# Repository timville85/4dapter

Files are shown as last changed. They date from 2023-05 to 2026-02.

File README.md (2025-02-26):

# 4dapter
### Open Source Controller Adapter for Nintendo Switch / MiSTer / XInput / Batocera / RetroArch

This project combines the NES, SNES, N64 and Genesis DaemonBite Retro Controllers projects together with a custom PCB to support 4 different controllers with a single socketed Arduino Pro Micro. PCB (KiCad + Gerbers), 3D Cases, and muliple firmware versions (Arduino code) all available in this repository.





PCB Kits + Fully Assembled units (with firmware of your choice) available on [Tindie](https://www.tindie.com/products/31785/)

3 different firmware versions are available in this repo:
* Default: Optimized for MiSTer, PC, Raspberry Pi, etc. - reports as 3 separate controllers (NES/SNES combined) and supports multiplayer from a single unit.
* Analogue Pocket: Optimized for Pocket Dock - reports as a single wired XInput device.
* Nintendo Switch: Optimized for Nintendo Switch Online NES, SNES, and Genesis collections - reports as a single wired switch controller.

**MiSTer Users - Important Info:** For maximum compatibly, install the MiSTer controller Map file found in the [MiSTer Maps Folder](https://github.com/timville85/4dapter/tree/main/MiSTer%20Maps) to your `/media/fat/config/inputs` directory on your MiSTer SD card and reboot your MiSTer. After doing this, you'll need to map the N64 controller in the N64 core for all buttons to work. The SNES / Genesis / NES cores will already be properly configured via the Map file.

## Resources and Thanks

**Special thanks to** [Dinierto Designs](https://twitter.com/DiniertoDesigns) **and** [Super Retro City X](https://twitter.com/SuperRetroCity) **for their assistance during development and testing of the 4dapter. Also thanks to** [Mechevarria](https://github.com/mechevarria) **for Batocera support and testing.**

**3D Case files were also designed by** [Dinierto Designs](https://twitter.com/DiniertoDesigns) **and are available in the 3D Cases folder.**

* [DaemonBite Retro Controllers](https://github.com/MickGyver/DaemonBite-Retro-Controllers-USB)
* https://github.com/esden/pretty-kicad-libs
* https://github.com/ddribin/nes-port-breadboard
* https://github.com/Biacco42/ProMicroKiCad
* http://www.neshq.com/hardgen/powerpad.txt
* https://www.instructables.com/Use-an-Arduino-with-an-N64-controller/

See individual README files in firmware folders for more specific instructions on button assignments and firmware configurations.

## Wiring Diagram
3dapter _ 4dapter Controller Wiring (1)

Current Draw Readings from DIO Pin 16 (used for 5v supply for DB9 port):
* Krikzz Joyzz:	38mA
* 8BitDo M30 2.4G: 29mA
* OEM SEGA 3-Button Wired: 3mA
* OEM SEGA 6-Button Wired: 3mA
* Retrobit 6-Button Wired: 2mA
(Arduino DIO Max Rated Current: 40mA)

## Tested Controllers

The following controllers have been personally tested and are supported with the Triple Controller. All listed devices also fit when using the 3D Case as well.

NES:
* OEM NES Controller
* OEM NES PowerPad (Default FW Only)
* 8BitDo N30 2.4G Receiver
* 8BitDo NES Retro Receiver

SEGA / Genesis:
* OEM SEGA Master System 2-Button Controller
* OEM Genesis 3-Button Controller
* OEM Genesis 6-Button Controller
* 8BitDo M30 2.4G Receiver
* 8BitDo Genesis Retro Receiver
* Krikzz Joyzz

SNES:
* OEM SNES Controller
* OEM SFC Controller
* OEM SNES NTT Controller (Default FW Only)
* 8BitDo SN30 2.4G Receiver
* 8BitDo SNES Retro Receiver

N64:
* OEM N64 Controller
* Retro Fighters Brawler64 V1/V2
* Retro Fighters Brawler64 Wireless Edition

## 4dapter Bill of Materials (BOM)

4dapter was designed with all components to be through-hole soldered to make the project as accessible as possible.

* **1x 4dapter Main Board**

* **1x 4dapter N64 Daugher Board**

* **1x SNES Socket (90 deg):** [AliExpress - Gamers Zone Store](https://www.aliexpress.com/item/32838396935.html) 

* **1x NES Socket:** [AliExpress - Gamers Zone Store](https://www.aliexpress.com/item/1005003699734963.html)

* **1x Genesis Socket:** [AliExpress - Gamers Zone Store](https://www.aliexpress.com/item/1005003699497865.html)

* **1X N64 Socket:** [AliExpress - Gamers Zone Store](https://www.aliexpress.us/item/3256803534347876.html)

* **1x Arduino Pro Micro (USB-C 3-15V Version):** [AliExpress](https://www.aliexpress.us/item/2251832700923799.html)

* **1x 1x3 90 Degree Male Header:** [Digi-Key](https://www.digikey.com/en/products/detail/sullins-connector-solutions/PREC003SBAN-M71RC/2774931)

* **1x 3.3v Regulator (MCP1700-3302E/TO):** [Digi-Key](https://www.digikey.com/en/products/detail/microchip-technology/MCP1700-3302E-TO/652680)

* **2x 1uF Capacitor:** [Digi-Key](https://www.digikey.com/en/products/detail/tdk-corporation/FG18X5R1H105KRT06/5802871) 

* **1x 6mm x 6mm x 5mm Push Button:** [Digi-Key](https://www.digikey.com/en/products/detail/te-connectivity-alcoswitch-switches/1825910-6/1632536)

* **2x 1x12 Female Header:** [Digi-Key](https://www.digikey.com/en/products/detail/sullins-connector-solutions/PPTC121LFBN-RC/807231)

* **5x M2x10mm Screws for 3D Case**




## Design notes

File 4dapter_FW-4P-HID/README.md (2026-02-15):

# 4dapter - 4 Player HID Firmware variation for MiSTer / PC

This firmware reports **four controller ports as separate USB HID gamepads** (four players on one device):

- **Gamepad 0:** NES  
- **Gamepad 1:** SNES  
- **Gamepad 2:** Genesis  
- **Gamepad 3:** N64  

**Recommended for MiSTer:** This 4-endpoint firmware is designed and optimized for MiSTer FPGA devices, where all four controller ports are correctly recognized. For PC or browser use, fewer endpoints may appear (see [Windows](#windows-only-3-controllers-visible-same-firmware-shows-4-on-maclinux) and [browser](#browser-gamepad-api) limitations below).

To get all four endpoints, **CDC (USB serial) must be disabled** at build time. See [Build setup (4 HID endpoints)](#build-setup-4-hid-endpoints) below.

**Windows:** On Windows, only 3 controller endpoints may appear even with correct firmware—this may be a [Windows limitation](#windows-only-3-controllers-visible-same-firmware-shows-4-on-maclinux).

---

## Build Setup (4 HID Endpoints)

The ATmega32U4 has limited USB endpoints. With serial (CDC) enabled, only three HID gamepads are available and the N64 port will not appear. To get all four gamepads you must build the Arduino AVR core with `CDC_DISABLED`.

### 1. Copy `platform.local.txt` into the AVR platform folder

This folder includes **`platform.local.txt`**. Copy it into the **same folder as the AVR platform** your Arduino IDE uses.

To find that folder: enable **File → Preferences → Show verbose output during compilation**, then compile once and look for a line like **“Using core ... from platform in folder: ...”**. The path is the folder that should contain `platform.local.txt`.

Example (your path may differ by OS or Arduino version):

- **macOS:** `~/Library/Arduino15/packages/arduino/hardware/avr/1.8.7/`
- **Windows:** `%LOCALAPPDATA%\Arduino15\packages\arduino\hardware\avr\1.8.7\`
- **Linux:** `~/.arduino15/packages/arduino/hardware/avr/1.8.7/`

**If you build on multiple computers (e.g. Mac and Windows), you must add `platform.local.txt` and clear the build cache on each machine.** Otherwise you may see 4 controller endpoints on one and only 3 on the other, because the firmware was compiled with different options (CDC on vs off).

Copy the **`platform.local.txt`** from this folder into that AVR folder (so the file sits next to `platform.txt`).

### 2. Clear the build cache and recompile

The IDE may still use an old core built without `-DCDC_DISABLED`. After adding `platform.local.txt`:

1. Quit the Arduino IDE.
2. Delete the build cache folder (its path appears in the verbose compile output as **“-build-cache ...”**).
3. Reopen the IDE, open this sketch, and run **Sketch → Verify/Compile**.

In the verbose log you should see **`-DCDC_DISABLED`** when the core is compiled. Then all four HID gamepads (including N64) will register.

### 3. Uploading (no serial port)

With CDC disabled, the board no longer appears as a serial port. To upload:

1. Start upload from the IDE.
2. When it says “Uploading…”, **press the reset button** on the 4dapter PCB. The board enters the bootloader and the upload completes.

---

## Windows: only 3 controllers visible (same firmware shows 4 on Mac/Linux)

If the **same 4dapter hardware** (with 4-endpoint firmware already flashed) shows **4 controller endpoints on macOS or Linux** but only **3 on Windows**, this appears to be a **Windows limitation**, not a firmware bug.

The device correctly reports 4 HID interfaces and 4 endpoints (verified with USBView: `bNumInterfaces = 4`, `wTotalLength` validated, all 4 interface and endpoint descriptors present). Windows’ USB composite parent driver (Usbccgp.sys) and HID stack only create 3 child devices for the 4 interfaces. IADs were tried but reverted—`bInterfaceCount=1` is invalid per USB spec and did not resolve the issue. The firmware uses plain interface descriptors and is spec-compliant.

**Things to try on Windows (may or may not help):**

1. **Device Manager** — Expand **Human Interface Devices** and **Universal Serial Bus devices**. Check how many 4dapter entries appear and whether any show a yellow warning.
2. **USB port** — Plug directly into a **motherboard USB port** (not a hub).
3. **Driver** — If an interface appears under **Other devices** or with a warning, try **Update driver** → **Let me pick** → **HID-compliant game controller** or **USB Input Device**.
4. **Verify descriptor** — Use [USBView](https://learn.microsoft.com/en-us/windows-hardware/drivers/usbcon/usbview-example) or [USB Device Tree Viewer](https://www.uwe-sieber.de/usbtreeview.html). If `bNumInterfaces = 4` and all 4 interfaces/endpoints are present with no errors, the firmware is correct; the limitation is in Windows’ enumeration.

### Browser (Gamepad API)

In browser gamepad testers (e.g. [Hardware Tester](https://hardwaretester.com/gamepad)) using the Gamepad API:

- **Chrome on macOS:** Only **1** controller may appear. The 4dapter is one USB composite device; Chrome on Mac often exposes a single gamepad slot per device, so only one of the four ports is visible.
- **Chrome on Windows:** **3** controllers typically appear, matching the 3 HID interfaces that Windows enumerates for this device.

This is browser/OS behavior, not a firmware bug. Click on the page (user gesture) and press a button on a connected port so the browser can detect the controller.

### Custom descriptor with IADs (reference)

IADs group **two or more** interfaces into one function; `bInterfaceCount` must be &gt; 1 per USB spec. With one interface per gamepad, IAD cannot be used correctly—each IAD would need `bInterfaceCount=1`, which USBView flags as an error. This section documents the format for reference only. Each interface remains **HID** (`bInterfaceClass = 0x03`). Each interface keeps `bInterfaceClass = 0x03` (HID); the IAD is an extra descriptor that *precedes* each interface and tells the host “the following interface(s) form one function.” That helps Windows’ composite driver create one PDO per gamepad. The host still loads the standard HID driver for each interface; games and apps still see four HID game controllers.

**Current layout (no IAD):**  
For each of the four gamepads, the configuration descriptor contains:

1. **Interface descriptor** (9 bytes) — `bInterfaceClass = 0x03` (HID), one interface, one endpoint.
2. **HID descriptor** (class-specific) — report descriptor length, etc.
3. **Endpoint descriptor** (7 bytes) — interrupt IN.

So today: `[Interface][HID][Endpoint]` × 4. No IAD.

**With IAD (custom descriptor):**  
Before each of those blocks you prepend an **IAD** (8 bytes) that describes “one function = one HID interface”:

| Offset | Field | Value (per gamepad) | Meaning |
|---|---|---|---|
| 0 | bLength | 8 | IAD size |
| 1 | bDescriptorType | 0x0B | INTERFACE_ASSOCIATION |
| 2 | bFirstInterface | 0, 1, 2, or 3 | Interface number for this pad |
| 3 | bInterfaceCount | 1 | One interface in this function |
| 4 | bFunctionClass | 0x03 | HID |
| 5 | bFunctionSubClass | 0x00 | No subclass |
| 6 | bFunctionProtocol | 0x00 | No protocol |
| 7 | iFunction | 0 | No string (or index if you add one) |

So each gamepad’s block becomes: **`[IAD][Interface][HID][Endpoint]`**. The Interface descriptor is unchanged: still class 0x03 (HID), so the device still reports as a HID device. Only the configuration descriptor gains four 8-byte IADs; the rest (HID report descriptor, endpoints, behavior) stays the same.

**Example IAD bytes for interface 0 (NES):**  
`08 0B 00 01 03 00 00 00`

- `08` = length 8  
- `0B` = IAD  
- `00` = bFirstInterface 0  
- `01` = bInterfaceCount 1  
- `03 00 00` = HID, no subclass, no protocol  
- `00` = iFunction 0  

For interfaces 1–3 you’d use `08 0B 01 01 03 00 00 00`, `08 0B 02 01 03 00 00 00`, `08 0B 03 01 03 00 00 00`.

**Optional device descriptor change:**  
Some hosts expect composite devices that use IADs to use device class **EFh** (Miscellaneous), subclass **02h** (Common Class), protocol **01h** (Interface Association). That is a device-level hint that IADs are present; the interfaces remain HID (0x03). If you implement a fully custom descriptor set, you can set `bDeviceClass=0x00` (composite) as today, or `0xEF/0x02/0x01` if you want to follow that convention.

**Summary:** A custom descriptor that adds IADs would still report four HID interfaces; only the configuration descriptor layout changes. The device would still be a standard HID gamepad device to the host and to games.

---

## MiSTer - Define Joystick Buttons (Mapping)

In the MiSTer main menu, use the N64 controller for the steps below; NES / SNES / Genesis will then align for their cores:

```
DPAD Test: Press RIGHT     ---  D-Right
Stick 1 Test: Tilt RIGHT   ---  Analog Stick Right
Stick 1 Test: Tilt DOWN    ---  Analog Stick Down
Stick 2 Test: Tilt RIGHT   ---  Undefine (User / Space to Skip)
Press: RIGHT               ---  Analog Stick Right
Press: LEFT                ---  Analog Stick Left
Press: DOWN                ---  Analog Stick Down
Press: UP                  ---  Analog Stick Up
Press: A                   ---  A Button
Press: B                   ---  B Button
Press: X                   ---  C-Down Button
Press: Y                   ---  C-Left Button
Press: L                   ---  Left Bumper Button
Press: R                   ---  Right Bumper Button
Press: Select              ---  C-Right Button
Press: Start               ---  Start Button
Press: Mouse Move RIGHT    ---  Undefine (User / Space to Skip)
Press: Mouse Move LEFT     ---  Undefine (User / Space to Skip)
Press: Mouse Move DOWN     ---  Undefine (User / Space to Skip)
Press: Mouse Move UP       ---  Undefine (User / Space to Skip)
Press: Mouse Btn Left      ---  Undefine (User / Space to Skip)
Press: Mouse Btn Right     ---  Undefine (User / Space to Skip)
Press: Mouse Btn Middle    ---  Undefine (User / Space to Skip)
Press: Mouse Emu/Sniper    ---  Undefine (User / Space to Skip)
Press: Menu                ---  C-Right Button + Analog Stick Down
Note: C-Right Button + Analog Stick Down makes Select/Mode + Down work for NES/SNES/GEN
      This may cause menu to appear in some gameplay, so adapt as needed.
Press: Menu: OK            ---  A Button
Press: Menu: Back          ---  B Button
Stick 1: Tilt RIGHT        ---  Analog Stick Right
Stick 1: Tilt DOWN         ---  Analog Stick Down
```

---

## Controller Button Mapping

To keep button mapping consistent on MiSTer, map the SNES controller in the MiSTer main menu; NES and Genesis will then align to their core defaults.

```
     NES    PowerPad  SNES     GEN(normal)  N64
-------------------------------------------------------
X    U/D    N/A       U/D      U/D          Stick U/D
Y    L/R    N/A       L/R      L/R          Stick L/R
01   B      Pad 01    B        B            B
02   A      Pad 02    A        A            A
03   N/A    Pad 03    Y        Y            C-Left
04   N/A    Pad 04    X        X            C-Down
05   N/A    Pad 05    L        Z            L
06   N/A    Pad 06    R        C            R
07   SELECT Pad 07    SELECT   MODE         C-Right
08   START  Pad 08    START    START        START
09   N/A    Pad 09    NTT 0    HOME(8BitDo) Z
10   N/A    Pad 10    NTT 1    N/A          D-Up
11   N/A    Pad 11    NTT 2    N/A          D-Down
12   N/A    Pad 12    NTT 3    N/A          D-Left
13   N/A    N/A       NTT 4    N/A          D-Right
14   N/A    N/A       NTT 5    N/A          C-Up
15   N/A    N/A       NTT 6    N/A          N/A 
16   N/A    N/A       NTT 7    N/A          N/A
17   N/A    N/A       NTT 8    N/A          N/A
18   N/A    N/A       NTT 9    N/A          N/A
19   N/A    N/A       NTT *    N/A          N/A
20   N/A    N/A       NTT #    N/A          N/A
21   N/A    N/A       NTT .    N/A          N/A
22   N/A    N/A       NTT C    N/A          N/A
23   N/A    N/A       N/A      N/A          N/A
24   N/A    N/A       NTT End  N/A          N/A
```

---

## MiSTer Home Menu Suggestion

If you use the [mapping steps](#mister---define-joystick-buttons-mapping) above (with Menu → C-Right Button + Analog Stick Down for N64), then:

* **N64:** C-Right Button + Analog Stick Down  
* **NES:** SELECT + DOWN  
* **SNES:** SELECT + DOWN  
* **GENESIS:** MODE + DOWN  

*Note: SELECT + DOWN = HOME on 8BitDo N30*

---

## RetroArch Port Binding

The 4dapter appears as one USB device with four controller indices. In RetroArch, set **Settings → Input → Port 1 Binds → Device Index** and choose the index for the port you want (e.g. #4 for N64, #1–#3 for NES/SNES/Genesis). Save; it applies per game, core, or content directory.

- https://retropie.org.uk/forum/topic/26681/port-binds/
- https://retropie.org.uk/docs/RetroArch-Configuration/#core-input-remapping

---

## Install Instructions

### 1. Complete build setup (4 HID endpoints)

Follow [Build Setup (4 HID endpoints)](#build-setup-4-hid-endpoints) above: copy **`platform.local.txt`** into the AVR platform folder and clear the build cache.

### 2. Board and upload

1. In the Arduino IDE, select **Tools → Board → Arduino AVR Boards → Arduino Leonardo**.
2. Open this sketch and compile (Sketch → Verify/Compile).
3. Upload using the reset-button method described in step 3 of Build Setup.

---

## Restoring Firmware After Alternative Firmware

If you previously flashed Analogue Pocket or Nintendo Switch firmware, the board may no longer show as a serial port. The 4dapter HID firmware (with CDC disabled) also does not use serial.

To upload or restore firmware:

1. Open this project in the Arduino IDE.
2. Connect the 4dapter via USB.
3. Start upload (Sketch → Upload).
4. When the IDE says “Uploading…”, **press the reset button** on the 4dapter PCB. The board enters the bootloader and the upload should complete. If the port is not found, try the upload and reset sequence again.

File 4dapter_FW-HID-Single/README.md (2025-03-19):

# 4dapter - HID Firmware (Single) for Batocera / PC

The default HID firmware will allow the 4dapter to appear as a single controller with all 4 inputs merged into one.

## [Batocera](https://batocera.org/)
This firmware will allow usage of the 4dapter in Batocera by **default** - no code changes are required for this flavor of the 4dapter firmware. 

This compatibility happens by setting 2 lines to `false`. The first is in [4dapter_FW-HID-Single.ino](4dapter_FW-HID-Single.ino)
```c++
#define N64Mister       false
```

The second is in [SegaController32U4.h](SegaController32U4.h)
```c++
#define GEN_MISTER       false
```

NES, SNES, Genesis controllers will be mapped automatically for immediate use. N64 controllers will need to be re-mapped in Retroarch (Mupen64Plus-Next) according to the diagram below
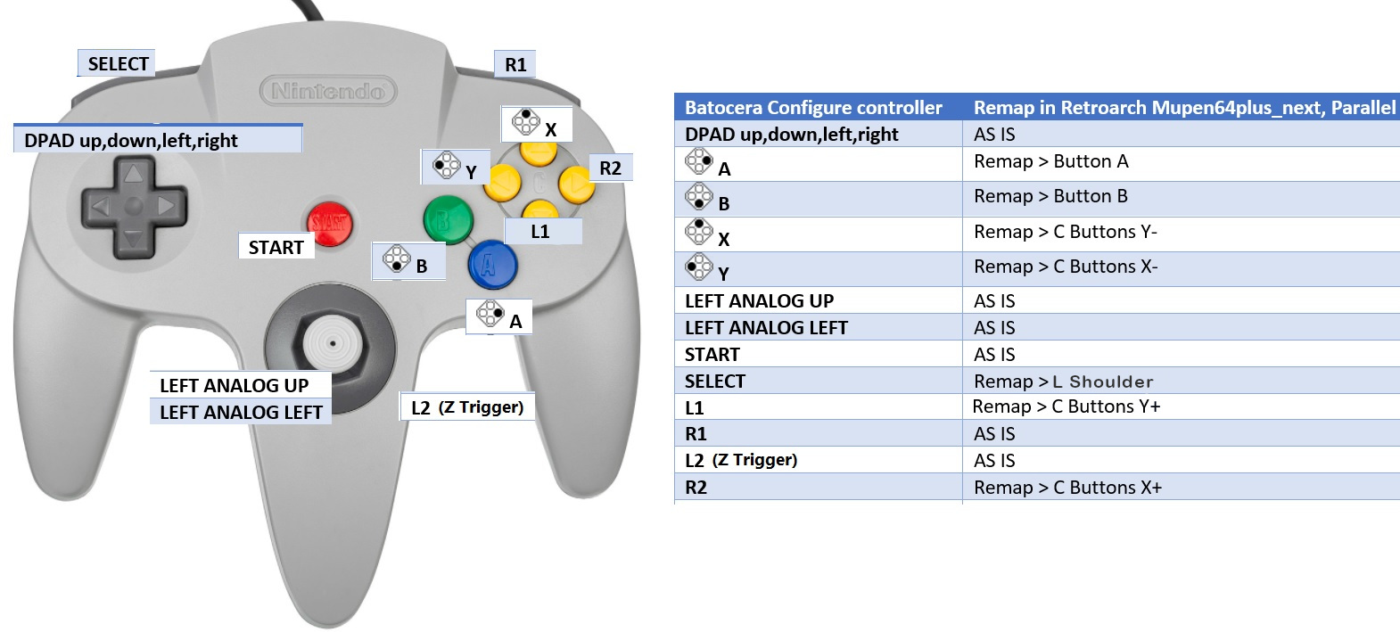
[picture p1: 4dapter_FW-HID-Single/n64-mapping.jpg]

An example re-map for player 1 is in [Mupen64Plus-Next.rmp](Mupen64Plus-Next.rmp) which can be manually copied to `/userdata/system/.config/retroarch/config/remaps/Mupen64Plus-Next`

### Older versions of Batocera
This mapping will be added to Batocera in version 42+ but can be manually added to your `/userdata/system/configs/emulationstation/es_input.cfg` with the content in [es_last_input.cfg](es_last_input.cfg)

## MiSTer - Define Joystick Buttons (Mapping)

### Manual Mapping
If manually mapping in the MiSTer main menu, use the N64 controller using the following steps and NES / SNES / Genesis will be appropriately mapped for their cores:

```
DPAD Test: Press RIGHT     ---  D-Right
Stick 1 Test: Tilt RIGHT   ---  Analog Stick Right
Stick 1 Test: Tilt DOWN    ---  Analog Stick Down
Stick 2 Test: Tilt RIGHT   ---  Undefine (User / Space to Skip)
Press: RIGHT               ---  Analog Stick Right
Press: LEFT                ---  Analog Stick Left
Press: DOWN                ---  Analog Stick Down
Press: UP                  ---  Analog Stick Up
Press: A                   ---  A Button
Press: B                   ---  B Button
Press: X                   ---  C-Down Button
Press: Y                   ---  C-Left Button
Press: L                   ---  Left Bumper Button
Press: R                   ---  Right Bumper Button
Press: Select              ---  C-Right Button
Press: Start               ---  Start Button
Press: Mouse Move RIGHT    ---  Undefine (User / Space to Skip)
Press: Mouse Move LEFT     ---  Undefine (User / Space to Skip)
Press: Mouse Move DOWN     ---  Undefine (User / Space to Skip)
Press: Mouse Move UP       ---  Undefine (User / Space to Skip)
Press: Mouse Btn Left      ---  Undefine (User / Space to Skip)
Press: Mouse Btn Right     ---  Undefine (User / Space to Skip)
Press: Mouse Btn Middle    ---  Undefine (User / Space to Skip)
Press: Mouse Emu/Sniper    ---  Undefine (User / Space to Skip)
Press: Menu                ---  C-Right Button + Analog Stick Down
Note: C-Right Button + Analog Stick Down makes Select/Mode + Down work for NES/SNES/GEN
      This may cause menu to appear in some gameplay, so adapt as needed.
Press: Menu: OK            ---  A Button
Press: Menu: Back          ---  B Button
Stick 1: Tilt RIGHT        ---  Analog Stick Right
Stick 1: Tilt DOWN         ---  Analog Stick Down
```

## Controller Button Mapping

```
     NES    PowerPad  SNES     GEN(normal)  GEN(MiSTer)  N64
-------------------------------------------------------------------
X    U/D    N/A       U/D      U/D          U/D          Stick U/D
Y    L/R    N/A       L/R      L/R          L/R          Stick L/R
01   B      Pad 01    B        B            A            B
02   A      Pad 02    A        A            B            A
03   N/A    Pad 03    Y        Y            X            C-Left
04   N/A    Pad 04    X        X            Y            C-Down
05   N/A    Pad 05    L        Z            Z            L
06   N/A    Pad 06    R        C            C            R
07   SELECT Pad 07    SELECT   MODE         MODE         C-Right
08   START  Pad 08    START    START        START        START
09   N/A    Pad 09    NTT 0    HOME(8BitDo) [SPECIAL]    Z
10   N/A    Pad 10    NTT 1    N/A          N/A          D-Up
11   N/A    Pad 11    NTT 2    N/A          N/A          D-Down
12   N/A    Pad 12    NTT 3    N/A          N/A          D-Left
13   N/A    N/A       NTT 4    N/A          N/A          D-Right
14   N/A    N/A       NTT 5    N/A          N/A          C-Up
15   N/A    N/A       NTT 6    N/A          N/A          N/A
16   N/A    N/A       NTT 7    N/A          N/A          N/A
17   N/A    N/A       NTT 8    N/A          N/A          N/A
18   N/A    N/A       NTT 9    N/A          N/A          N/A
19   N/A    N/A       NTT *    N/A          N/A          N/A
20   N/A    N/A       NTT #    N/A          N/A          N/A
21   N/A    N/A       NTT .    N/A          N/A          N/A
22   N/A    N/A       NTT C    N/A          N/A          N/A
23   N/A    N/A       N/A      N/A          N/A          N/A
24   N/A    N/A       NTT End  N/A          N/A          N/A

* GENESIS(MiSTer): Mode will send Select + Down
```

## MiSTer Home Menu Suggestion
* **NES:** SELECT + DOWN
* **SNES:** SELECT + DOWN
* **GENESIS:** MODE + DOWN

*Note: SELECT + DOWN = HOME on 8BitDo N30*

## MiSTer mode on 8bitdo M30 controller

MiSTer mode can be toggled on and off with "HOME + Z" (you have to press HOME first, Z second). This setting is saved to EEPROM and preserved across power cycles. The default is "normal mode".

When the Genesis controller is in MiSTer mode:

- The HOME button sends "DOWN + MODE" (This is because no equivalent of the HOME button exists on the other controller ports)

- Buttons are swapped: A with B and X with Y. This is such that the position of the buttons is consistent between SNES and Genesis.

## Install Instructions
You can update the firmare using [Arduino IDE](https://www.arduino.cc/en/software)

From Arudino IDE, `file -> open` then select [4dapter_FW-HID-Single](4dapter_FW-HID-Single)

### 1. Select "Arduino AVR Boards - Arduino Leonardo" from Boards List
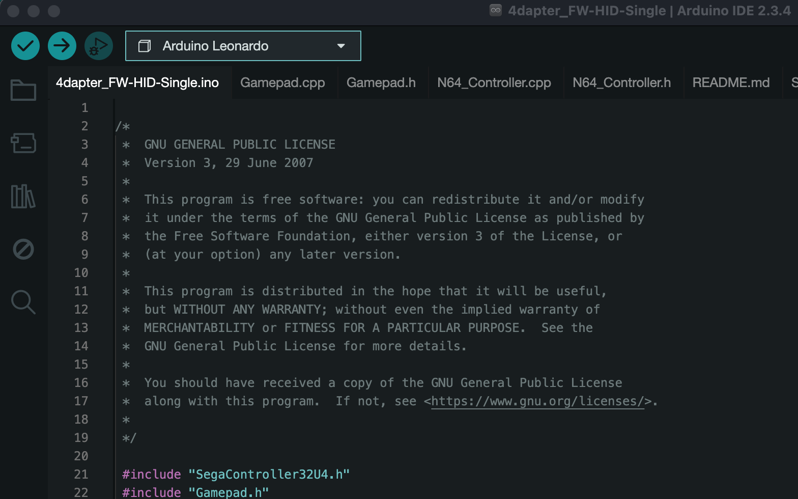
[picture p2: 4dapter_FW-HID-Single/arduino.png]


### 2. Download project to Arduino Pro Micro board
Select `upload` in the Arduino IDE
> You will need to manually reset by pressing the tip of a flatheader screwdriver for 1 second on the board after selecting `upload` by following the instructions below 

## Restoring Firmware After Alternative Firmware Downloads

If you previously used the Analogue Pocket or Nintendo Switch firmware versions, your Arduino Pro Micro will no longer report as a Serial device and will not appear in the "Port" list in the Arduino software. Using the default 3dapter firmware does not suffer from this issue.

To restore the default firmware for your Arduino Pro Micro, you will need to manually reset the Arduino Pro Micro by shorting the Reset + Ground pins together to trigger a reset. 

1. Open the default firmware project in the Arduino software.
2. Connect your Arduino Pro Micro to your computer.
3. Trigger the download from the Arduino software. The Arduino software will first compile the project before beginning the download.
4. Once the "compiling" step has finished, trigger a reset on the Arduino Pro Micro by briefly touching the Reset (RST) and Ground (GND) pins together. This should make the Arduino forcefully switch into bootloader mode and allow the download to complete. If the download fails initially due to not finding the COM port, repeat the download/reset process and it should work the second time.

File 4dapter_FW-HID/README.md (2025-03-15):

# 4dapter - HID Firmware for MiSTer / PC

The default HID firmware will allow the 4dapter to appear a multiplayer input controller with 3 controller inputs acting as it's own separate player/input (NES and SNES are combined due to Arduino USB endpoint limitations.)

## MiSTer - Define Joystick Buttons (Mapping)

### Via .map File
For maximum compatibly, install the MiSTer controller Map file found in the [MiSTer Maps Folder](https://github.com/timville85/4dapter/tree/main/MiSTer%20Maps) to your `/media/fat/config/inputs` directory on your MiSTer SD card and reboot your MiSTer. After doing this, you'll need to map the N64 controller in the N64 core for all buttons to work. The SNES / Genesis / NES cores will already be properly configured via the Map file, so do not map the individual cores or else conflicts may occur.

### Manual Mapping 
If manually mapping in the MiSTer main menu, use the N64 controller using the following steps and NES / SNES / Genesis will be appropriately mapped for their cores:
```
DPAD Test: Press RIGHT     ---  D-Right
Stick 1 Test: Tilt RIGHT   ---  Analog Stick Right
Stick 1 Test: Tilt DOWN    ---  Analog Stick Down
Stick 2 Test: Tilt RIGHT   ---  Undefine (User / Space to Skip)
Press: RIGHT               ---  Analog Stick Right
Press: LEFT                ---  Analog Stick Left
Press: DOWN                ---  Analog Stick Down
Press: UP                  ---  Analog Stick Up
Press: A                   ---  A Button
Press: B                   ---  B Button
Press: X                   ---  C-Down Button
Press: Y                   ---  C-Left Button
Press: L                   ---  Left Bumper Button
Press: R                   ---  Right Bumper Button
Press: Select              ---  C-Right Button
Press: Start               ---  Start Button
Press: Mouse Move RIGHT    ---  Undefine (User / Space to Skip)
Press: Mouse Move LEFT     ---  Undefine (User / Space to Skip)
Press: Mouse Move DOWN     ---  Undefine (User / Space to Skip)
Press: Mouse Move UP       ---  Undefine (User / Space to Skip)
Press: Mouse Btn Left      ---  Undefine (User / Space to Skip)
Press: Mouse Btn Right     ---  Undefine (User / Space to Skip)
Press: Mouse Btn Middle    ---  Undefine (User / Space to Skip)
Press: Mouse Emu/Sniper    ---  Undefine (User / Space to Skip)
Press: Menu                ---  C-Right Button + Analog Stick Down
Note: C-Right Button + Analog Stick Down makes Select/Mode + Down work for NES/SNES/GEN
      This may cause menu to appear in some gameplay, so adapt as needed.
Press: Menu: OK            ---  A Button
Press: Menu: Back          ---  B Button
Stick 1: Tilt RIGHT        ---  Analog Stick Right
Stick 1: Tilt DOWN         ---  Analog Stick Down
```

## Controller Button Mapping

To maintain proper button mapping on MiSTer, it's recommended to map the SNES controller on the MiSTer Main menu and the NES / Genesis controllers will align to their core defaults properly.

```
     NES    PowerPad  SNES     GEN(normal)  GEN(MiSTer)  N64
-------------------------------------------------------------------
X    U/D    N/A       U/D      U/D          U/D          Stick U/D
Y    L/R    N/A       L/R      L/R          L/R          Stick L/R
01   B      Pad 01    B        B            A            B
02   A      Pad 02    A        A            B            A
03   N/A    Pad 03    Y        Y            X            C-Left
04   N/A    Pad 04    X        X            Y            C-Down
05   N/A    Pad 05    L        Z            Z            L
06   N/A    Pad 06    R        C            C            R
07   SELECT Pad 07    SELECT   MODE         MODE         C-Right
08   START  Pad 08    START    START        START        START
09   N/A    Pad 09    NTT 0    HOME(8BitDo) [SPECIAL]    Z
10   N/A    Pad 10    NTT 1    N/A          N/A          D-Up
11   N/A    Pad 11    NTT 2    N/A          N/A          D-Down
12   N/A    Pad 12    NTT 3    N/A          N/A          D-Left
13   N/A    N/A       NTT 4    N/A          N/A          D-Right
14   N/A    N/A       NTT 5    N/A          N/A          C-Up
15   N/A    N/A       NTT 6    N/A          N/A          N/A
16   N/A    N/A       NTT 7    N/A          N/A          N/A
17   N/A    N/A       NTT 8    N/A          N/A          N/A
18   N/A    N/A       NTT 9    N/A          N/A          N/A
19   N/A    N/A       NTT *    N/A          N/A          N/A
20   N/A    N/A       NTT #    N/A          N/A          N/A
21   N/A    N/A       NTT .    N/A          N/A          N/A
22   N/A    N/A       NTT C    N/A          N/A          N/A
23   N/A    N/A       N/A      N/A          N/A          N/A
24   N/A    N/A       NTT End  N/A          N/A          N/A

* GENESIS(MiSTer): Mode will send Select + Down
```

## MiSTer Home Menu Suggestion
* **NES:** SELECT + DOWN
* **SNES:** SELECT + DOWN
* **GENESIS:** MODE + DOWN

*Note: SELECT + DOWN = HOME on 8BitDo N30*

## MiSTer mode on 8bitdo M30 controller

The 4dapter exposes three "players" on one USB device.  Unfortunately MiSTer does not support setting keymaps per "player", MiSTer mode works around this by making sure the positional mapping is the same between all controllers.

MiSTer mode can be toggled on and off with "HOME + Z" (you have to press HOME first, Z second). This setting is saved to EEPROM and preserved across power cycles. The default is "normal mode".

When the Genesis controller is in MiSTer mode:

- The HOME button sends "DOWN + MODE" (This is because no equivalent of the HOME button exists on the other controller ports)

- Buttons are swapped: A with B and X with Y. This is such that the position of the buttons is consistent between SNES and Genesis.

## Retroarch Port Binding

Some Retroarch users have reported issues regarding setting the correct “Device Index” setting, since the 3dapter reports a single “device” to RetroArch with 3 different controllers, each as their own “index”.

In Retroarch, go to Settings → Input → Port 1 Binds → Device Index and then choose #3 for N64 and presumably #1 or #2 for NES/SNES and Genesis. Save and it sticks for that game, core or content directory.

https://retropie.org.uk/forum/topic/26681/port-binds/
https://retropie.org.uk/docs/RetroArch-Configuration/#core-input-remapping

## Install Instructions

### 1. Select "Arduino AVR Boards - Arduino Leonardo" from Boards List

### 2. Download project to Arduino Pro Micro board

## Restoring Firmware After Alternative Firmware Downloads

If you previously used the Analogue Pocket or Nintendo Switch firmware versions, your Arduino Pro Micro will no longer report as a Serial device and will not appear in the "Port" list in the Arduino software. Using the default 3dapter firmware does not suffer from this issue.

To restore the default firmware for your Arduino Pro Micro, you will need to manually reset the Arduino Pro Micro by shorting the Reset + Ground pins together to trigger a reset. 

1. Open the default firmware project in the Arduino software.
2. Connect your Arduino Pro Micro to your computer.
3. Trigger the download from the Arduino software. The Arduino software will first compile the project before beginning the download.
4. Once the "compiling" step has finished, trigger a reset on the Arduino Pro Micro by briefly touching the Reset (RST) and Ground (GND) pins together. This should make the Arduino forcefully switch into bootloader mode and allow the download to complete. If the download fails initially due to not finding the COM port, repeat the download/reset process and it should work the second time.

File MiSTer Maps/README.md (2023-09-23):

# 4dapter - MiSTer Map Files

**For maximum compatibly, install the MiSTer controller Map file found in the MiSTer Maps Folder to your `/media/fat/config/inputs` directory on your MiSTer SD card and reboot your MiSTer**

### Firmware button layouts for N64 controllers were updated on September 23rd 2023
Please update your firmware using the Arduino IDE software to use the `Latest` folder map files , otherwise please use the `Pre Sept 23 2023 FW` folder map file!

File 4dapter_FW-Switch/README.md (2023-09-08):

# 4dapter - Nintendo Switch Firmware

This firmware will allow the 4dapter to appear a single Switch-compatible controller. All 4 controller inputs will share the same singular player input (i.e. use only one controller at time). 

The controller inputs have been mapped to align to map to the Nintendo Switch Virtual NES, SNES, N64 and Genesis apps. Switch-specific button combos have been added to support in-game menus, home buttons, and screenshot capabities.

## IMPORTANT NOTE
**Installing the XInput Library will remove the self-reset listener from the Arduino board. This means you will need to manually reset the Arduino when updating the code on the board or switching to a different firmware.**

**You can accomplish this by connecting the RST and GND pins together - a tip of a screwdriver works well since the pins are next to each other.**



## 4dapter Special Buttons for Switch

**NES:**
* In-Game Menu ("-" Button): Select + D-Pad Down
* Home Button: Select + Start
* Screenshot: Select + Up

**SNES:**
* In-Game Menu ("-" Button): Select + D-Pad Down
* Home Button: Select + Start
* Screenshot: Select + Up

**Genesis (6-Button Mode):**
* In-Game Menu ("-" Button): Mode + Down
* Home Button: Mode + Start (or 8BitDo M30 Heart Button)
* Screenshot: Mode + D-Pad Up
* Special Mode to Swap Genesis X --> Switch RB (for SEGA Genesis Classics): Hold Mode + B for 1.5 Seconds

**Genesis (3-Button Mode):**
* In-Game Menu ("-" Button): Start + A + B + C
* Home Button: Start + A + Down
* Screenshot: Start + A + Up

**N64:**
* In-Game Menu ("-" Button): Start + D-Pad Down
* Home Button: Start + L-Button + R-Button
* Screenshot: Start + D-Pad Up
* Special Mode to Swap N64 B --> Switch X (for Super Mario 3D All-Stars): Hold Start + D-Pad Down for 1.5 Seconds

**NES / SNES / Genesis 6-Button:**
Swap Directional Pad <--> Left Analog Joystick Toggle
* Hold Select/Mode + Down for 1.5 seconds
* Reports 8-Way Input (Cardinal + Diagonal)

## Resources Used

* [LUFA Arduino Board & Library](https://github.com/CrazyRedMachine/Arduino-Lufa)
* [Switch-Fightstick](https://github.com/progmem/Switch-Fightstick).

## Install Instructions

### 1. Add the following URL as an Additional Board Manager URL (in File -> Preferences menu)
`https://github.com/CrazyRedMachine/Arduino-Lufa/raw/master/package_arduino-lufa_index.json`

### 2. Select and Install **`LUFA AVR Boards`** from the Arduino Board Manager

### 3. Select **`Arduino LUFA AVR Boards -> Arduino Leonardo (LUFA)`** from Boards list

### 4. Download project to Arduino Pro Micro board

Remember after download your Arduino Pro Micro will no longer report as a Serial device and will not appear in the "Port" list in the Arduino software.

Note: If you are replacing existing code on the 4dapter, trigger the download from the Arduino software and then trigger a reset on the Arduino Pro Micro within a few seconds of starting the download. If the download fails initially due to not finding the COM port, repeat the download/reset process and it should work the second time.

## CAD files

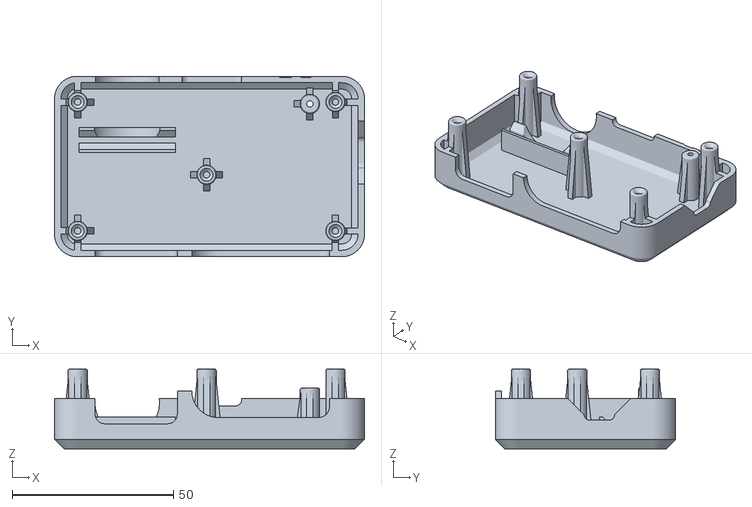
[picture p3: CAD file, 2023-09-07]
3D Cases/4dapter - USB-C 35-36mm Top Case.stl
96.2 x 56.0 x 24.8

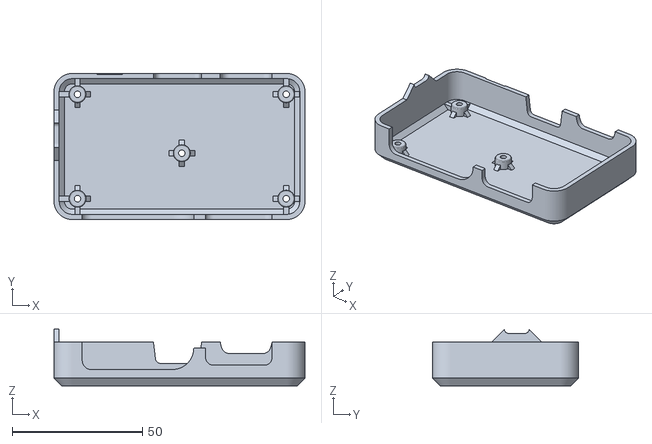
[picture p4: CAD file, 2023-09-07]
3D Cases/4dapter - USB-C 35-36mm Bottom Case.stl
96.2 x 56.0 x 21.7

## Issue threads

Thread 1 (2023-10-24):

4x N64 Adapter with rumble suppprt?

RyanMac84, 2023-10-24:
Is it possible to have 4x N64 controllers all with rumble support?

timville85, 2023-10-24:
Rumble is not currently supported. 4 4dapters connected to the same device should work just fine, however.

Closed 2024-11-27.

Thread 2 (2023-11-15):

Love the design but just need N64

zezretro, 2023-11-15:
Hiya

I need just the N64 part and I live way on the other side of Europe so shipping is a lot

I would happily use a Arudino and wire in the N64 port. I see the issue is with providing 3.3V and thats what the extra components on the pcb do.

If I just wanted to wire in a N64 port in the jankiest way possible, what components would I use between the "RAW" pin and the 3.3V on the N64 port?

thank you!

timville85, 2023-11-16:
https://www.digikey.com/en/products/detail/stmicroelectronics/LD1117V33/586012

Connect Arduino "RAW" to "V In"
Connect Arduino "GND" to "GND"

Connect N64 3.3V to "V Out"
Connect N64 "GND" to "GND"
Connect N64 Data to Arduino Pin 10 (if using 4dapter code)

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

zezretro, 2023-11-17:
Thank you for this!

Closed 2023-12-18.

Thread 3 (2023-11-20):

N64 controller analog stick Issue with fast left to right movements

staticaland, 2023-11-20:
## Description

**Problem**: When moving the analog stick quickly from left to right on the N64 controller, the direction isn't registering correctly. This is a big issue in games like Mario Kart 64, especially when drifting.

**Expected**: The game should track the stick movements accurately, responding right away to changes in direction.

**Actual**: The game isn't responding properly to quick side-to-side movements of the stick.

## Steps to Reproduce

1. Play Mario Kart 64.
2. Try to drift by moving the stick quickly from side to side.
3. Notice the response in-game.

timville85, 2023-11-20:
Try updating to the latest firmware - There was an [issue](https://github.com/timville85/4dapter/commit/71547d03f5220ea4f39225e8aede2ae9bd2ea9e2) fixed where the X-axis was being scaled incorrectly.

Latest firmware is here: https://github.com/timville85/4dapter/tree/main/4dapter_FW-HID

staticaland, 2023-11-20:
This is fixed by updating the firmware. See https://github.com/timville85/4dapter/commit/71547d03f5220ea4f39225e8aede2ae9bd2ea9e2.

Below is what I did to upgrade the firmware.

# Step-by-Step Firmware Upgrade Process

## Step 1: Download Firmware Files

- First, navigate to the Daemonbite adapter firmware [GitHub repository](https://github.com/timville85/4dapter).
- Download the project as a ZIP file.
- Once downloaded, unzip the file to extract its contents.

## Step 2: Open the Firmware File

- Locate the `.ino` file [within the unzipped folder](https://github.com/timville85/4dapter/tree/main/4dapter_FW-HID).
- Open this file using the Arduino IDE. If you don't have the Arduino IDE installed, you can download it from the [official Arduino website](https://www.arduino.cc/en/software).

## Step 3: Select the Appropriate Port

- Connect your Daemonbite adapter to your computer.
- In the Arduino IDE, go to the `Tools` menu.
- Choose `Port` and select the port that corresponds to your connected Daemonbite adapter.

## Step 4: Select the Board

- Still in the `Tools` menu, navigate to `Board`.
- Select `Arduino Leonardo` from the list of available boards. This selection is crucial for compatibility with the Daemonbite firmware.

## Step 5: Upload the Firmware

- Once the correct port and board are selected, you can upload the firmware to your Daemonbite adapter.
- Click on the upload button in the Arduino IDE. This process will compile and upload the new firmware to your adapter.

## Step 6: Completion

- After the upload is complete, the IDE will display a message indicating successful firmware upload.
- Your Daemonbite adapter is now updated and ready to use with the new firmware.

staticaland, 2023-11-20:
Thanks @timville85! You are too fast, I had already fixed it and just wanted to create an issue for anyone else searching for a solution 😅

Closed 2023-11-20.

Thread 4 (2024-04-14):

lufa.h not found

DfknG, 2024-04-14:
When I was trying to write the switch firmware it references lufa.h but there is no file or directory specified.

4dapter-main\4dapter-main\4dapter_FW-Switch\4dapter_FW-Switch.ino:3:10: fatal error: LUFA.h: No such file or directory
 #include <LUFA.h>
          ^~~~~~~~
compilation terminated.
exit status 1

Compilation error: LUFA.h: No such file or directory

timville85, 2024-04-14:
Make sure you install the LUFA boards - instructions at the bottom of the Switch readme:

https://github.com/timville85/4dapter/blob/main/4dapter_FW-Switch/README.md

Closed 2024-08-09.

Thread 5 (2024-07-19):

No response on nintendo switch

Stefkeys, 2024-07-19:
I have uploaded the switch firmware to the 4dapter successfully. However, I am getting no response on the Nintendo switch.
I am trying to use the wireless 8bitdo controllers.
Are there some restrictions that I'm not aware of?

timville85, 2024-07-19:
Just confirming that you've selected the Arduino LUFA board type and also are installing the Switch project from the 4dapter repo?

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

Stefkeys, 2024-07-21:
So the issue turns out to be that I need to have the 4dapter plugged into the switch dock prior to booting the switch.

I have confirmed that it works.

Closed 2024-07-22.

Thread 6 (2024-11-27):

Gamecube controller support

steelpuxnastik, 2024-11-27:
I see in schematic device "supports" gamecube controller, but beyond this there is no mention of it. Is there some radical problems with it and will it be implemented? Because I'm super interested in it.
I see in some other projects about gamecube arduino used level shifter on data line.

timville85, 2024-11-27:
These ports were exposed (and provided on the PCB with a header) mostly for future use/experimentation. The idea was to provide a data path (to pin 4 on the Arduino) along with 5v / 3.3v / GND to wire in a Gamecube socket. The data line would likely need a level shifter added but a final proper implementation would include one.

Basically, it was added with the idea of potential future support, but no plans on officially supporting it any time soon.

steelpuxnastik, 2024-12-03:
That is why I asked you, because to add to this board additional board with level shifter, gamecube socket and so on not a big problem. I wanted to make it, but the only problem - it's support in firmware.

Closed 2024-11-27.

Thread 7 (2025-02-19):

Batocera configuration

mechevarria, 2025-02-19:
Just asking if you have any ideas on how to get this fantastic adapter to play nicely with [batocera.linux](https://batocera.org/)
I tried all the firmwares and each had their own pros/cons.
If you don't know already, the way Batocera works is that a controller is globally mapped once and that global config is automatically mapped to individual emulators like retroarch, mupen64 and so on (big python if/elseif/else block that writes to the individual emulator config)
Ideally the adapter would report as one controller with a unique vendor/pid that will allow global configuration in batocera without squashing the existing config for something like the Xbox controller.
Being playing around with the firmwares and config in Batocera for a couple days now and can't figure anything out yet. So I thought I would ask

timville85, 2025-02-22:
Try the new HID Single I just added - I did some quick testing and everything seemed OK, but let me know if you see anything.
https://github.com/timville85/4dapter/tree/main/4dapter_FW-HID-Single

mechevarria, 2025-02-22:
Wow that was fast! I'm checking it out now

mechevarria, 2025-02-22:
Tried HID single out. NES/SNES working perfect. 6 button Genesis controller coming Monday 😅. N64 I could not map the C buttons to the right axis. I could map up/down right axis but not left/right because the button the 'left C' button conflicted with the 'select' button. I don't know if these help but this is the mapping in Retroarch for an N64 controller

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

Using `sdl2-jstest --test 0` is the best way to see how Batocera interprets the board.

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

And then the config mapping in Batocera (that gets sent to Retroarch and other emulators). I could not define `joystick2left` (right analog) because the left C Button is `button 6` which is already in use by the `select` button

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

timville85, 2025-02-22:
Hmm... yeah, this was to prevent an issue on MiSTers that I moved the mapping for C-Right to match Select.

https://github.com/timville85/4dapter/blob/b6b8f35536ce4fb0b195e70be87a197fe33dde72/4dapter_FW-HID-Single/4dapter_FW-HID-Single.ino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

If you change the line above from "6" to "14" that should resolve that issue for you.

mechevarria, 2025-02-22:
Made the change. Shoot. The conflict is now with the 'y' button, button 2. 'Right Analog Left' which corresponds to `joystick2left` can't be mapped to button 2, since that is y. That also means that c-down as button 3 will conflict with the x button.

timville85, 2025-02-22:
You can see from the ReadMe the mapping across all of the controllers:

https://github.com/timville85/4dapter/tree/main/4dapter_FW-HID-Single#controller-button-mapping

So you can just edit the same section of code from above and assign the C buttons to different numbers (the 4dapter will report up to 24 buttons).

mechevarria, 2025-02-22:
ah, gotcha. I remapped the buttons and I'm trying things out.

mechevarria, 2025-02-23:
I'm slowly getting there with button remapping to the defaults in Batocera. I'll do a PR so nobody else has to figure this out. My only issue is that `Button 16` isn't registering an input at all when I use `sdl2-jstest --test0`. All the other buttons work

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

timville85, 2025-02-23:
Ah, just played around with it - weird issues with data type limits and the mask at the end of it.

Check out:
https://github.com/timville85/4dapter/blob/4e16090fe022e44d42dab1e562f366167f02f89a/4dapter_FW-HID-Single/4dapter_FW-HID-Single.ino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

Change this line to "false" and it should work for you by properly setting button 17.

mechevarria, 2025-02-23:
Almost done! Just need to test with a Genesis controller to verify the mapping is all good! I started documenting the changes  [here](https://github.com/mechevarria/4dapter/tree/main/4dapter_FW-HID-Single). I'll do a PR when done

mechevarria, 2025-02-25:
So what do I have to edit to remap the buttons for the Genesis controller? Dpad, mode and start are fine, the other button mapping needs to get updated. I just don't know where to edit

timville85, 2025-02-25:
Genesis is a bit more complex because there is no native remapping - it all lives here:
https://github.com/timville85/4dapter/blob/main/4dapter_FW-HID-Single/SegaController32U4.cpp

Are you trying to make the Genesis inputs align to separate buttons?  These are the default mappings to make everything align to the MiSTer Genesis core.
```
     NES    PowerPad  SNES     GEN(normal)  GEN(MiSTer)  N64
-------------------------------------------------------------------
X    U/D    N/A       U/D      U/D          U/D          Stick U/D
Y    L/R    N/A       L/R      L/R          L/R          Stick L/R
01   B      Pad 01    B        B            A            B
02   A      Pad 02    A        A            B            A
03   N/A    Pad 03    Y        Y            X            C-Left
04   N/A    Pad 04    X        X            Y            C-Down
05   N/A    Pad 05    L        Z            Z            L
06   N/A    Pad 06    R        C            C            R
```

You would have to break `currentState >> 4` up into a set of conditionals to determine what button to align to the button index set by the gamepad report. You can see an example of how this was done in the XInput version of the firmware:

https://github.com/timville85/4dapter/blob/4e16090fe022e44d42dab1e562f366167f02f89a/4dapter_FW-XInput/4dapter_FW-XInput.ino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

Basic gist is to do a bitwise comparison of the genesis data (currentState) and the enumeration defined in the header for the genesis system:
https://github.com/timville85/4dapter/blob/4e16090fe022e44d42dab1e562f366167f02f89a/4dapter_FW-XInput/SegaController32U4.h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

If you tell me what specific mappings you're looking for, I may be able to help.

mechevarria, 2025-02-25:
Yeah, more complex than I thought. This is the preferred mapping that Batocera/Retroarch does out of the box

| SNES    | Button  | Genesis|
| -------- | ------- | ------|
| B  | 0    | B|
| A | 1     | C|
| Y    | 2    | A|
| X  | 3    | Y|
| L | 4    | X|
| R    | 5    | Z|

timville85, 2025-02-25:
Figured out an easier way to do it by making an alternative version of the enum. Just set this line to "false" and it should match your table above:

https://github.com/timville85/4dapter/blob/ea854849146f82b89d4097c274ea56900ff2da0f/4dapter_FW-HID-Single/SegaController32U4.h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

mechevarria, 2025-02-25:
Just tested, Genesis mapping worked perfect! Let me get things cleaned up on my end and I'll put in a PR

timville85, 2025-02-26:
Great to hear it's working - Merged the PR in and clarified that the "Single" flavor is defaulted for Batocera support.

I also added Batocera as a pre-installed option on my Tindie store as well for assembled units.

Glad I could help and thanks for your support!

mechevarria, 2025-02-26:
It was super easy collaborating on this. This was great!

Closed 2025-02-26.

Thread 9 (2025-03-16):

Holding Button 6 does not register a hold input

mechevarria, 2025-03-16:
When holding `button 6` i.e. the `select` button on a controller with the (Batocera/Retroarch) firmware, it only registers as a quick press in-game instead of a button hold.

I verified with different controllers (N64, SNES) that its not a faulty controller. Verified that its not on the software end by using a 8Bitdo SN30 Pro wired and it properly registered a button hold with `select`.

The part that is confusing me is that if I run `sdl2-jstest` and test the input by holding down button 6 i.e. select, `sdl2-jstest` _does_ register the button press as a hold (value stays at 1). But in game it does not register as a button hold (tested with a button test rom), but just a quick press

I would test with a different button, but I don't know how to edit the Genesis mapping to keep in sync (mode = select)

timville85, 2025-03-17:
I'm not sure this is a firmware / Arduino code issue - I tested on Windows and can detect a full-hold, and also tested on MiSTer using the Batocera firmware and a full-hold was reported using the SNES core and a controller input test ROM - so I couldn't replicate this issue.

There's nothing in the code tied to the select button input (along with it happening on multiple controllers) that would be causing it to register as a quick press instead of a hold.

Is Select possibly tied to some menu hotkey? I'm wondering if it's being treated separately in the configuration that "holding" it is triggering some other setting / mode.

In terms of remapping Genesis, it's in this file - the enum defines the bitmask for the buttons.
https://github.com/timville85/4dapter/blob/9df2e5e986828cdebd58f983e854dc5352e66d20/4dapter_FW-HID-Single/SegaController32U4.h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

I've also commented the mapping below from the enum - you can just swap the values between buttons to move them around.

```
  SC_BTN_A     = 64,  //Button 2
  SC_BTN_B     = 16,  //Button 0
  SC_BTN_C     = 32,  //Button 1
  SC_BTN_X     = 256,  //Button 4
  SC_BTN_Y     = 128,  //Button 3
  SC_BTN_Z     = 512,  //Button 5
  SC_BTN_MODE  = 1024,  //Button 6
  SC_BTN_START = 2048,  //Button 7
  SC_BTN_HOME  = 4096,  //Button 8
```

mechevarria, 2025-03-17:
Shoot. Something is odd. Button 6 or `select` is a hotkey. So I wonder if that is the issue. So to test if I use a higher button, I just double the value to go up the buttons? Like button 9 would be 8192?

mechevarria, 2025-03-17:
Yep. Conflcting with the Batocera hotkey is causing the issue. I moved the hotkey to a shoulder button and now that won't register as a hold.

Closed 2025-03-17.

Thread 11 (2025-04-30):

Not working (SOLVED)

RetrogamerItalia, 2025-04-30:
Hi, can I ask you for help? I made the whole kit from me, I proceeded to assemble everything but, if I only connect the Arduino to the PC, it is recognized as a normal Joypad Xbox, while if I connect the Arduino while it is grafted on the 4Dapter, the lights make a quick flashing without lighting and the adapter is not recognized by the PC. Could you please help me?
Thanks

mmmonkeyPete, 2025-04-30:
I had exactly the same recently, and the cause was a faulty 3.3v voltage regulator, swapped it out and then everything worked fine.

timville85, 2025-04-30:
I would agree - usually this indicate either a short somewhere or a faulty regulator that is basically keeping the Arduino from booting.

RetrogamerItalia, 2025-04-30:
Thanks, I'll try to replace the regulator, hoping that's it. Because I tried to assemble a new kit, and that one also doesn't work by chance.

RetrogamerItalia, 2025-04-30:
> I had exactly the same recently, and the cause was a faulty 3.3v voltage regulator, swapped it out and then everything worked fine.

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

 Without regulator it works, I tried all the ones you see in the picture, but if I connect them even just by placing them on the contacts, Arduino turns off. It seems strange to me that they are all defective.
1700 3302E TO 53916G

timville85, 2025-04-30:
That doesn't sound like a defective 3.3v regulator but rather a short in the soldering somewhere else. Can you post a photo of the underside of the board?

mmmonkeyPete, 2025-04-30:
I did have a bad batch of 10 regulators myself, can’t remember where I got them from, but replaced with some from a more reputable shop and it was fine.

Absolutely check for a short too though! I found the regulator itself the difficult part to solder and not get a short.

RetrogamerItalia, 2025-04-30:
> That doesn't sound like a defective 3.3v regulator but rather a short in the soldering somewhere else. Can you post a photo of the underside of the board?

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

 I checked with the tester if there are short circuits, but apparently there are none, the only thing I noticed is that as soon as I put the regulator in contact on the 3 pins, it turns off. I assembled 2 of them and both have the same problem.

Grazie tanto per l'aiuto 🙏🏼

RetrogamerItalia, 2025-04-30:
> That doesn't sound like a defective 3.3v regulator but rather a short in the soldering somewhere else. Can you post a photo of the underside of the board?

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

 This is the second kit, but with the same problem, I also tried not to solder the regulator by putting the pins bent so as to ensure contact, but the problem is the same.

Thanks

RetrogamerItalia, 2025-04-30:
> I did have a bad batch of 10 regulators myself, can’t remember where I got them from, but replaced with some from a more reputable shop and it was fine.
>
> Absolutely check for a short too though! I found the regulator itself the difficult part to solder and not get a short.

 Tomorrow I'll try buying new regulators from a different store.

 Let's hope so, this thing is depressing, I just wish I could use my old controllers on PC with Batocera. 😒

Thanks for your help

RetrogamerItalia, 2025-05-01:
This morning I checked the regulators, they are all faulty. I will buy other regulators from a different store, and I will surely fix it. Thanks so much for the help

I will let you know

@timville85
@mmmonkeyPete

RetrogamerItalia, 2025-05-10:
SOLVED: the datasheet of the regulator was wrong, the poles were reversed. For anyone in front of my own problem, I recommend checking that:

1) That the regulator is not burned, using a multimeter and a smartphone power supply with 5V output (looking frontally the regulator where the writer presents, with the feet down, the contacts are, starting from the right, GND - 5v (in) - 3V (OUT).

2) There are no short circuits in welds.

Thank you for help to:

@timville85  and @mmmonkeyPete

Closed 2025-05-10.

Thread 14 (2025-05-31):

Firmware Issues

Slypty, 2025-05-31:
After writing the FW, the Port no longer appears since this is a Arduino Leopard as XInput Build.

 I'm having trouble with my 4Adapter, the issue is erratic.  It could be a faulty PCB, or maybe how my Mr. Pi interacts with the 4Adapter.

  I'm more worried about burning 4 ATMega32U4s with no ability to get them back to a working state.

 Is there a way to have IDE recognize them easily after burning the XInput FW?  It would really help me at this point, thanks

timville85, 2025-05-31:
You can flash a blank Arduino project back to the Micro to get out of xinput mode.

Change back to the normal Arduino Leonardo board type - then basically after you hit the "upload" button in the Arduino software, press the reset button on the 4dapter board.

This should trigger the bootloader and allow the default configuration to be restored. The Arduino should now appear as a normal serial port device.

Give your comments in the other issue, it seems like your PCBs may have been defective - Where did you order them from?

Slypty, 2025-05-31:
I've Ordered from 3 different places, all with the same results.  (AliExpress twice and Amazon).  I had the 4Adapter functioning as it should over PC with the GamePad Tester website, no issues for 20 minutes.  Plugged it in to my Mr. Pi, and it started to bug out with random scrolls and intermittent contact.

  So I removed it from the Mr. Pi and retried it with the PC.  Now I have almost all buttons being hit with out touching them.  By removing the Arduino from the 4Adapter, the problem might go away but comes back, even after draining power from the 4Adapter.  Same thing when programming a new ATMega after using the 4Adapter with the Mr. Pi, acting buggy for some reason.

timville85, 2025-05-31:
You can still reflash the arduinos unplugged from the 4dapter - you'll need to follow the same steps as before, but use a screw or other small conductive material to touch the reset and ground pins on the Arduino together momentarily to trigger a reset.

I haven't heard of anyone else having these issues before, so I'm wondering if the 4dapter PCBs (and not the arduinos) you have are somehow defective?

In theory if it's working on a PC it should work on the MiSTer Pi, but I'm not sure if the MiSTer Pi uses a different USB stack or anything that might be causing issues. I do have one but I haven't set it up yet, I'll try to do over the next week.

Slypty, 2025-05-31:
Thanks I managed to reflash the Arduino's.  Reselect the Board type was my issue.

  I'm beginning to think my flux becomes more conductive as it dries.  I cleaned it up more and the board is acting as intended again, it had a temporary B button issue but that went away after a few minutes.

  It seems OK on my PC for now, I have a real MiSTerFPGA I could test it with tomorrow, for now I don't want to plug it in to the Mr. Pi quite yet.

Slypty, 2025-06-02:
Couldn't get to my MiSTer, but on the Mr. Pi Clone it started to work fine after I removed the keyboard from the USB hub.  There was the occasional hiccup but it was good enough to play with, the leftover flux might have had a small impact but for the majority it's this Mr. Pi's parasitic interaction with the USB Hub, keyboard and 4adapter

timville85, 2025-06-03:
Glad to hear things are working - some flux can be conductive, so it's best to remove as much of it as possible. I usually clean boards I build with 99% Isopropyl alcohol.

Closed 2025-06-02.

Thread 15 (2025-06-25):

Feature request: use the NES64 pcb shape + wii ext

insaner, 2025-06-25:
Hi, just found this project (so awesome, btw!) while hunting for a solution to what I'm trying to do. I first found https://gitlab.com/nes64/NES64  and was reaching out to the author, and in writing up my message I found your project!

In short, I want to use the NES64 board just to "fill in" my old nes controller casing that has no board, so I can use the original buttons which I still have. But I had also purchased the snes and nes (and wii ext) ports to test some old controllers I have. So I figured why not just modify the NES64 to add the holes and traces needed for this, and I can just use one board design for all purposes.

So my feature request is: would it be possible to use the NES64 shape (and dimensions) and existing traces, and add the traces and functionality you already have done for 4dapter? And perhaps even add traces and drill holes for the wii ext connector as well?

I have no pcb design capabilities, and a hunt for how to do that in linux yields unsatisfactory results (either I can only convert to gerber, but not edit, or only view gerber files, but not edit) so I doubt I will be able to do this myself.

thanks again!

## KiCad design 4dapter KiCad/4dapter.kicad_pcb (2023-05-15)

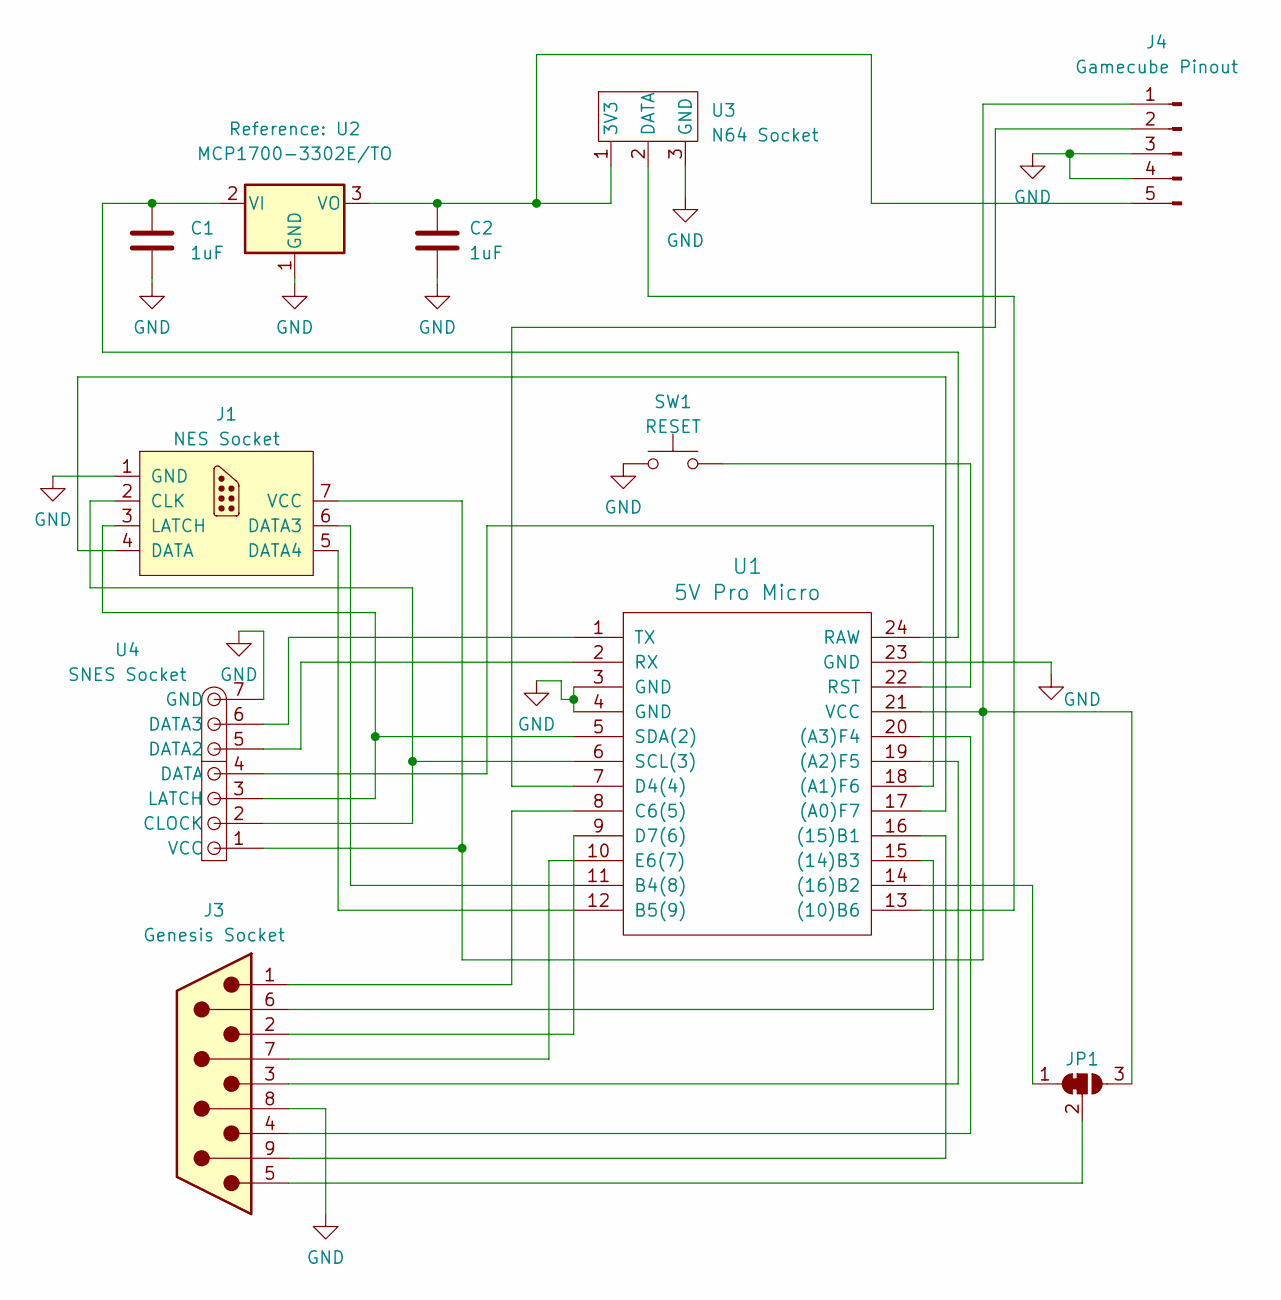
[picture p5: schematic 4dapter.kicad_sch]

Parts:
C1, C2: 1uF; C_Rect_L4.0mm_W2.5mm_P2.50mm
J1: NES Socket; NES 90 Socket
J3: Genesis Socket; Genesis 90 Socket
J4: Gamecube Pinout; PinHeader_1x05_P2.54mm_Vertical
JP1: SolderJumper_3_Bridged12; SolderJumper-3_P1.3mm_Bridged12_RoundedPad1.0x1.5mm_NumberL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
SW1: RESET; SW_PUSH_6mm
U1: 5V Pro Micro; Pro Micro Headers
U2: MCP1700-3302E/TO; TO-92_Inline
U3: N64 Socket; N64 Daughter Board
U4: SNES Socket; SNES 90 Socket

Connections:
GND: C1.2, C2.2, J1.1 (GND), J3.8, J4.3, J4.4, SW1.1, U1.3 (GND), U1.4 (GND), U1.23 (GND), U2.1 (GND), U3.3 (GND), U4.7 (GND); also elsewhere on the board
unnamed: J1.2 (CLK), U1.6 (SCL(3)), U4.2 (CLOCK)
unnamed: J1.6 (DATA3), U1.11 (B4(8))
unnamed: J1.5 (DATA4), U1.12 (B5(9))
unnamed: J1.4 (DATA), U1.17 ((A0)F7)
unnamed: J1.3 (LATCH), U1.5 (SDA(2)), U4.3 (LATCH)
unnamed: J1.7 (VCC), J4.1, JP1.3 (B), U1.21 (VCC), U4.1 (VCC)
unnamed: J4.2, U1.7 (D4(4))
unnamed: C2.1, J4.5, U2.3 (VO), U3.1 (3V3)
unnamed: JP1.1 (A), U1.14 ((16)B2)
unnamed: J3.5, JP1.2 (C)
unnamed: U1.13 ((10)B6), U3.2 (DATA)
unnamed: J3.6, U1.15 ((14)B3)
unnamed: J3.9, U1.16 ((15)B1)
unnamed: U1.18 ((A1)F6), U4.4 (DATA)
unnamed: J3.3, U1.19 ((A2)F5)
unnamed: J3.4, U1.20 ((A3)F4)
unnamed: J3.1, U1.8 (C6(5))
unnamed: J3.2, U1.9 (D7(6))
unnamed: J3.7, U1.10 (E6(7))
unnamed: C1.1, U1.24 (RAW), U2.2 (VI)
unnamed 21: SW1.2, U1.22 (RST); also elsewhere on the board
unnamed: U1.2 (RX), U4.5 (DATA2)
unnamed: U1.1 (TX), U4.6 (DATA3)

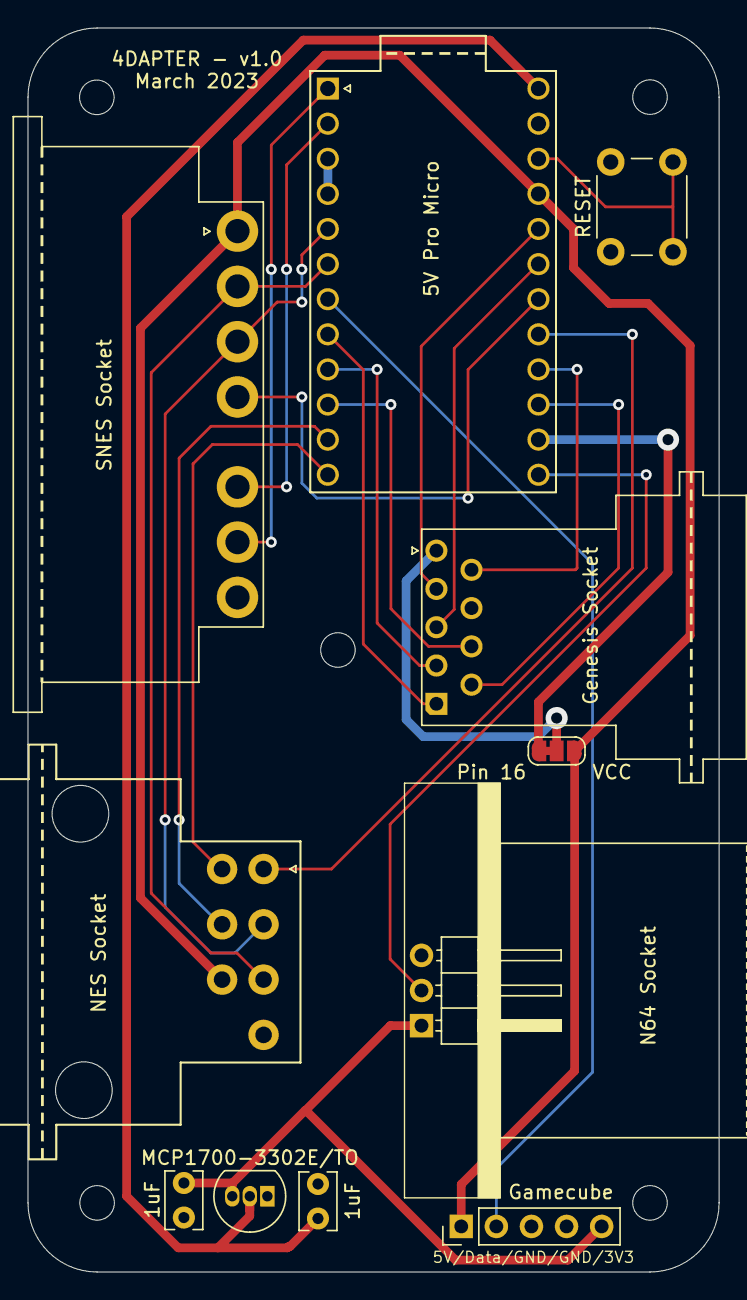
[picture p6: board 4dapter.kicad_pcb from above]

Board: 2 copper layers, 50.0 x 90.0 mm, 11 parts (0 on the bottom side), 24 nets.

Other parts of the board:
RESET: RESET; SW_PUSH_6mm

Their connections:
GND: RESET.1; also elsewhere on the board
unnamed 21: RESET.2; also elsewhere on the board

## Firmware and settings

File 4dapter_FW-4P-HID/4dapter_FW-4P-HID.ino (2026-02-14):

/*
 * 4dapter HID Firmware — main sketch (NES, SNES, Genesis, N64 → 4× USB HID gamepads)
 *
 * Copyright (C) 2026 4dapter project
 *
 * Original implementations for each controller type are credited in the
 * corresponding source files (Gamepad, SegaController32U4, N64_Controller).
 *
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
 * You should have received a copy of the GNU General Public License
 * along with this program.  If not, see <https://www.gnu.org/licenses/>.
 */

#include "SegaController32U4.h"
#include "Gamepad.h"
#include "N64_Controller.h"

#if !defined(CDC_DISABLED)
#warning "CDC_DISABLED is not defined. Only 3 HID endpoints will be available (4th/N64 will not appear). Copy platform.local.txt to the AVR core folder and clear build cache. See README.md."
#endif

// USB serial string (max 20 chars including NULL). Used to identify this device to the host.
const char* usbSerialNumber = "4DAPTER";

// N64 analog stick: map to full HID range (-128..127) when true; raw controller value when false.
#define N64_MAP_JOY_TO_MAX    true
#define N64_JOY_MAX           80   // Stick physical range (0-127; OEM typically 75-85)
#define N64_JOY_DEADZONE      3    // Center deadzone to reduce drift

N64Controller n64Controller;
N64_status_packet n64StatusPacket;
int8_t n64StickXHid = 0;  // N64 stick X sent to host as HID axis
int8_t n64StickYHid = 0;  // N64 stick Y sent to host as HID axis

// Port indices: NES and SNES share the same shift-register protocol.
#define PORT_NES     0
#define PORT_SNES    1
#define PORT_GENESIS 2

#define INDEX_BUTTONS  0
#define INDEX_AXES     1

// D-pad axis bits (used for NES/SNES/Genesis d-pad -> HID stick).
#define DPAD_UP    0x01
#define DPAD_DOWN  0x02
#define DPAD_LEFT  0x04
#define DPAD_RIGHT 0x08

#define NTT_INDICATOR_BIT  0x00   // SNES NTT (multitap/keypad) indicator
#define SHIFT_BIT_NO_DATA  0x00   // This shift bit is unused / no button

// HID axis values when mapping d-pad to virtual stick
#define HID_AXIS_CENTER  0
#define HID_AXIS_POS     0x7F
#define HID_AXIS_NEG     (int8_t)0x80

void sendLatch();
void sendClock();
void sendState();

/** Set gamepad report from buttons and d-pad axes (UP/DOWN/LEFT/RIGHT bit layout). */
static void setReportFromButtonsAndDpad(GamepadReport* report, uint32_t buttons, uint32_t dpadAxes)
{
  report->buttons = buttons;
  report->Y = (dpadAxes & DPAD_DOWN) ? HID_AXIS_POS : (dpadAxes & DPAD_UP) ? HID_AXIS_NEG : HID_AXIS_CENTER;
  report->X = (dpadAxes & DPAD_RIGHT) ? HID_AXIS_POS : (dpadAxes & DPAD_LEFT) ? HID_AXIS_NEG : HID_AXIS_CENTER;
}

/** Convert N64 stick value to HID axis with optional deadzone and range mapping. */
static int8_t n64StickToHid(int8_t rawStickValue, bool mapToFullRange)
{
  if (rawStickValue >= -N64_JOY_DEADZONE && rawStickValue <= N64_JOY_DEADZONE)
    return 0;
  if (mapToFullRange)
  {
    if (rawStickValue > N64_JOY_MAX)  rawStickValue = N64_JOY_MAX;
    if (rawStickValue < -N64_JOY_MAX) rawStickValue = -N64_JOY_MAX;
    return (int8_t)map(rawStickValue, -N64_JOY_MAX, N64_JOY_MAX, -128, 127);
  }
  return rawStickValue;
}

/*
 * Controller DB9 pinout (view: face-on to the plug)
 *
 *     Pin layout:    5  4  3  2  1
 *                    9  8  7  6
 *
 * Wiring (Triple Controller V1/V2; *** = change from V1 to V2):
 *
 *   Function          V1        V2        Notes
 *   ---------         --------  -------- --------------------
 *   VCC               VCC       VCC
 *   GND               GND       GND
 *   Shared LATCH      PD1 (2)   PD1 (2)
 *   Shared CLOCK      PD0 (3)   PD0 (3)
 *   NES Data1         PF7 (A0)  PF7 (A0)
 *   NES Data D4       N/C       PB5 (9)  ***
 *   NES Data D3       N/C       PB4 (8)  ***
 *   SNES Data1        PF6 (A1)  PF6 (A1)
 *   SNES Data D2      N/C       PD2 (RX) ***
 *   SNES Data D3      N/C       PD3 (TX) ***
 *   DB9-1             PC6 (5)   PC6 (5)
 *   DB9-2             PD7 (6)   PB2 (6)  ***
 *   DB9-3             PF5 (A2)  PF5 (A2)
 *   DB9-4             PF4 (A3)  PF4 (A3)
 *   DB9-5 (VCC)       VCC       PB2 (16) ***
 *   DB9-6             PB3 (14)  PB3 (14)
 *   DB9-7             PE6 (7)   PE6 (7)
 *   DB9-8 (GND)       GND       GND
 *   DB9-9             PB1 (15)  PB1 (15)
 */

/*
 * NES Power Pad button numbering (reference: http://www.neshq.com/hardgen/powerpad.txt)
 *
 *   SIDE B (top view):
 *   +--------------------------------+
 *   |  SIDE B                        |
 *   |   ___ ___ ___ ___               |
 *   |  | 1 | 2 | 3 | 4 |              |
 *   |   --- --- --- ---               |
 *   |   ___ ___ ___ ___               |
 *   |  | 5 | 6 | 7 | 8 |              |
 *   |   --- --- --- ---               |
 *   |   ___ ___ ___ ___               |
 *   |  | 9 |10 |11 |12 |              |
 *   |   --- --- --- ---               |
 *   +--------------------------------+
 *
 *   SIDE A (top view):
 *   +--------------------------------+
 *   |  SIDE A                        |
 *   |   ___ ___                       |
 *   |  | B3 | B2 |  (top row)        |
 *   |   --- ---                       |
 *   |   ___ ___ ___ ___               |
 *   |  | B8 | R7 | R6 | B5 |          |
 *   |   --- --- --- ---               |
 *   |   ___ ___                       |
 *   |  |B11 |B10 |  (bottom row)     |
 *   |   --- ---                       |
 *   +--------------------------------+
 */

// Four USB HID gamepads (4 endpoints = 4 players): [0]=NES, [1]=SNES, [2]=Genesis, [3]=N64.
Gamepad_ Gamepad[4];
SegaController32U4 genesisController;

// NES/SNES: shift-register state [port][buttons=0 or axes=1]. Filled one bit per clock.
uint32_t nesSnesData[2][2] = {{0, 0}, {0, 0}};
// For each of 32 shift bits: 1 = d-pad axis, 0 = button (bits 4-7 = NES/SNES d-pad).
uint32_t shiftBitIsDpadAxis[32] = {
  0, 0, 0, 0, 1, 1, 1, 1, 0, 0, 0, 0, 0, 0, 0, 0,
  0, 0, 0, 0, 0, 0, 0, 0, 0, 0, 0, 0, 0, 0, 0, 0
};
uint16_t genesisControllerState = 0;   // Current Genesis/MD controller buttons + d-pad
bool isNttControllerDetected = false;   // SNES NTT (multitap/keypad) present

// NES: mask for each of 8 shift bits -> button or d-pad bit
uint32_t nesShiftBitMask[8] = {
  0x02,       // bit 0: A
  0x01,       // bit 1: B
  0x40,       // bit 2: Start
  0x80,       // bit 3: Select
  DPAD_UP,    // bit 4: D-Up
  DPAD_DOWN,  // bit 5: D-Down
  DPAD_LEFT,  // bit 6: D-Left
  DPAD_RIGHT  // bit 7: D-Right
};

// NES Power Pad, data line D4 (shift bits 0..7 -> pad buttons)
uint32_t powerPadDataLine4Mask[8] = {
  0x08,   // #4
  0x04,   // #3
  0x800,  // #12
  0x80,   // #8
  SHIFT_BIT_NO_DATA, SHIFT_BIT_NO_DATA, SHIFT_BIT_NO_DATA, SHIFT_BIT_NO_DATA
};

// NES Power Pad, data line D3 (shift bits 0..7 -> pad buttons)
uint32_t powerPadDataLine3Mask[8] = {
  0x02,   // #2
  0x01,   // #1
  0x10,   // #5
  0x100,  // #9
  0x20,   // #6
  0x200,  // #10
  0x400,  // #11
  0x40    // #7
};

// SNES: mask for each of 32 shift bits -> button, d-pad, or NTT
uint32_t snesShiftBitMask[32] = {
  0x01,    // B
  0x04,    // Y
  0x40,    // Start
  0x80,    // Select
  DPAD_UP, DPAD_DOWN, DPAD_LEFT, DPAD_RIGHT,
  0x02,    // A
  0x08,    // X
  0x10,    // L
  0x20,    // R
  SHIFT_BIT_NO_DATA, NTT_INDICATOR_BIT, SHIFT_BIT_NO_DATA, SHIFT_BIT_NO_DATA,
  0x100, 0x200, 0x400, 0x800, 0x1000, 0x2000, 0x4000, 0x8000,
  0x10000, 0x20000, 0x40000, 0x80000, 0x100000, 0x200000,
  SHIFT_BIT_NO_DATA,
  0x800000   // NTT End Comms
};

void setup()
{
  // Brief delay so power and USB are stable before init.
  delay(50);

  n64Controller.N64_init();

  // N64 data pin: input with pull-up
  DDRD &= ~B00010000;
  PORTD |= B00010000;

  // NES/SNES shared latch and clock (PD1, PD0): output, low
  DDRD |= B00000011;
  PORTD &= ~B00000011;

  // NES/SNES data pins (A0, A1 / PF7, PF6): input with pull-up
  DDRF &= ~B11000000;
  PORTF |= B11000000;

  // NES Power Pad data pins (PB5, PB4): input with pull-up
  DDRB &= ~B00110000;
  PORTB |= B00110000;

  // DB9 pin 5 (VCC): output high
  DDRB |= B00000100;
  PORTB |= B00000100;

  delay(250);
}

void loop()
{
  while (true)
  {
    // Genesis 6-button: 8 read cycles per full state
    for (uint8_t cycle = 0; cycle < 8; cycle++)
      genesisControllerState = genesisController.updateState();
    genesisControllerState = genesisController.getFinalState();

    // Genesis -> Gamepad[2] (d-pad bit layout matches DPAD_*)
    setReportFromButtonsAndDpad(&Gamepad[2]._GamepadReport, genesisControllerState >> 4, genesisControllerState & 0x0F);

    sendLatch();

    nesSnesData[PORT_NES][INDEX_BUTTONS] = 0;
    nesSnesData[PORT_NES][INDEX_AXES] = 0;
    nesSnesData[PORT_SNES][INDEX_BUTTONS] = 0;
    nesSnesData[PORT_SNES][INDEX_AXES] = 0;
    isNttControllerDetected = false;

    for (uint8_t shiftBitIndex = 0; shiftBitIndex < 32; shiftBitIndex++)
    {
      if (!isNttControllerDetected && shiftBitIndex > 13)
        break;

      // NES Power Pad (data lines D4, D3)
      if ((shiftBitIndex < 8) && ((PINB & B00100000) == 0))
        nesSnesData[PORT_NES][INDEX_BUTTONS] |= powerPadDataLine4Mask[shiftBitIndex];
      if ((shiftBitIndex < 8) && ((PINB & B00010000) == 0))
        nesSnesData[PORT_NES][INDEX_BUTTONS] |= powerPadDataLine3Mask[shiftBitIndex];

      // NES controller (data line A0)
      if ((shiftBitIndex < 8) && ((PINF & B10000000) == 0))
      {
        if (shiftBitIsDpadAxis[shiftBitIndex])
          nesSnesData[PORT_NES][INDEX_AXES] |= nesShiftBitMask[shiftBitIndex];
        else
          nesSnesData[PORT_NES][INDEX_BUTTONS] |= nesShiftBitMask[shiftBitIndex];
      }

      // SNES / NTT controller (data line A1)
      if ((PINF & B01000000) == 0)
      {
        if (shiftBitIndex == 13)
          isNttControllerDetected = true;
        if (shiftBitIsDpadAxis[shiftBitIndex])
          nesSnesData[PORT_SNES][INDEX_AXES] |= snesShiftBitMask[shiftBitIndex];
        else
          nesSnesData[PORT_SNES][INDEX_BUTTONS] |= snesShiftBitMask[shiftBitIndex];
      }

      sendClock();
    }

    // NES -> Gamepad[0], SNES -> Gamepad[1]
    setReportFromButtonsAndDpad(&Gamepad[0]._GamepadReport,
        nesSnesData[PORT_NES][INDEX_BUTTONS], nesSnesData[PORT_NES][INDEX_AXES]);
    setReportFromButtonsAndDpad(&Gamepad[1]._GamepadReport,
        nesSnesData[PORT_SNES][INDEX_BUTTONS], nesSnesData[PORT_SNES][INDEX_AXES]);

    // N64 -> Gamepad[3]
    n64Controller.getN64Packet();
    n64StatusPacket = n64Controller.N64_status;

    Gamepad[3]._GamepadReport.X = 0;
    Gamepad[3]._GamepadReport.Y = 0;
    Gamepad[3]._GamepadReport.buttons = 0;

    n64StickXHid = n64StickToHid(n64StatusPacket.stick_x, N64_MAP_JOY_TO_MAX);
    n64StickYHid = n64StickToHid(-n64StatusPacket.stick_y, N64_MAP_JOY_TO_MAX);

    // N64 data2: L, R, C-pad
    Gamepad[3]._GamepadReport.buttons |= (n64StatusPacket.data2 & 0x20 ? 1 : 0) << 4;   // L
    Gamepad[3]._GamepadReport.buttons |= (n64StatusPacket.data2 & 0x10 ? 1 : 0) << 5;   // R
    Gamepad[3]._GamepadReport.buttons |= (n64StatusPacket.data2 & 0x08 ? 1 : 0) << 13;  // C-Up
    Gamepad[3]._GamepadReport.buttons |= (n64StatusPacket.data2 & 0x04 ? 1 : 0) << 3;   // C-Down
    Gamepad[3]._GamepadReport.buttons |= (n64StatusPacket.data2 & 0x02 ? 1 : 0) << 2;   // C-Left
    Gamepad[3]._GamepadReport.buttons |= (n64StatusPacket.data2 & 0x01 ? 1 : 0) << 6;   // C-Right
    // N64 data1: A, B, Z, Start, d-pad
    Gamepad[3]._GamepadReport.buttons |= (n64StatusPacket.data1 & 0x80 ? 1 : 0) << 1;   // A
    Gamepad[3]._GamepadReport.buttons |= (n64StatusPacket.data1 & 0x40 ? 1 : 0) << 0;   // B
    Gamepad[3]._GamepadReport.buttons |= (n64StatusPacket.data1 & 0x20 ? 1 : 0) << 8;   // Z
    Gamepad[3]._GamepadReport.buttons |= (n64StatusPacket.data1 & 0x10 ? 1 : 0) << 7;  // Start
    Gamepad[3]._GamepadReport.buttons |= (n64StatusPacket.data1 & 0x08 ? 1 : 0) << 9;   // D-Up
    Gamepad[3]._GamepadReport.buttons |= (n64StatusPacket.data1 & 0x04 ? 1 : 0) << 10; // D-Down
    Gamepad[3]._GamepadReport.buttons |= (n64StatusPacket.data1 & 0x02 ? 1 : 0) << 11;  // D-Left
    Gamepad[3]._GamepadReport.buttons |= (n64StatusPacket.data1 & 0x01 ? 1 : 0) << 12;  // D-Right

    Gamepad[3]._GamepadReport.buttons &= 0x0000FFFF;
    Gamepad[3]._GamepadReport.X = n64StickXHid;
    Gamepad[3]._GamepadReport.Y = n64StickYHid;

    sendState();
  }
}

void sendLatch()
{
  // Latch pulse on shared NES/SNES line (PD1)
  PORTD |= B00000010;
  __builtin_avr_delay_cycles(192);
  PORTD &= ~B00000010;
  __builtin_avr_delay_cycles(72);
}

void sendClock()
{
  // Clock pulse on shared NES/SNES line (PD0)
  PORTD |= B00000001;
  __builtin_avr_delay_cycles(96);
  PORTD &= ~B00000001;
  __builtin_avr_delay_cycles(72);
}

void sendState()
{
  // Push all four gamepad reports to the host (4th only if CDC disabled and endpoint registered).
  Gamepad[0].send();
  Gamepad[1].send();
  Gamepad[2].send();
  if (Gamepad[3].isPlugged())
  {
    Gamepad[3].send();
  }
  __builtin_avr_delay_cycles(16000);
}

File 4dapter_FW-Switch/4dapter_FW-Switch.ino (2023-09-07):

#include "LUFAConfig.h"
#include <LUFA.h>
#include "Joystick.h"
#include "SegaController32U4.h"
#include "N64_Controller.h"

uint32_t buttonStatus[18];

#define DPAD_UP_MASK_ON         0x00
#define DPAD_UPRIGHT_MASK_ON    0x01
#define DPAD_RIGHT_MASK_ON      0x02
#define DPAD_DOWNRIGHT_MASK_ON  0x03
#define DPAD_DOWN_MASK_ON       0x04
#define DPAD_DOWNLEFT_MASK_ON   0x05
#define DPAD_LEFT_MASK_ON       0x06
#define DPAD_UPLEFT_MASK_ON     0x07
#define DPAD_NOTHING_MASK_ON    0x08

#define Y_MASK_ON         0x01
#define B_MASK_ON         0x02
#define A_MASK_ON         0x04
#define X_MASK_ON         0x08
#define LB_MASK_ON        0x10
#define RB_MASK_ON        0x20
#define ZL_MASK_ON        0x40
#define ZR_MASK_ON        0x80
#define SELECT_MASK_ON    0x100
#define START_MASK_ON     0x200
#define L3_MASK_ON        0x400
#define R3_MASK_ON        0x800
#define HOME_MASK_ON      0x1000
#define CAPTURE_MASK_ON   0x2000

#define BUTTONUP      0
#define BUTTONDOWN    1
#define BUTTONLEFT    2
#define BUTTONRIGHT   3
#define BUTTONA       4
#define BUTTONB       5
#define BUTTONX       6
#define BUTTONY       7
#define BUTTONLB      8
#define BUTTONRB      9
#define BUTTONLT      10
#define BUTTONRT      11
#define BUTTONSTART   12
#define BUTTONSELECT  13
#define BUTTONHOME    14
#define BUTTONCAPTURE 15
#define BUTTONL3      16
#define BUTTONR3      17

#define NES       0
#define SNES      1
#define GENESIS   2

#define BUTTONS   0
#define AXES      1

#define UP        0x01
#define DOWN      0x02
#define LEFT      0x04
#define RIGHT     0x08

#define NTT_BIT   0x00
#define NODATA    0x00

long LeftX = 0;
long LeftY = 0;
long RightX = 0;
long RightY = 0;

bool Swap_DPAD_JOY = false;
bool Swap_N64_Button = false;
bool Swap_Gen_Button = false;
#define toggleDelay 1500

//Set N64 Joystick Maximum Travel Range (0-127, typically between 75-85 on OEM controllers)
#define N64JoyMax 80

void sendLatch();
void sendClock();
void sendState();
void processInputs();

// Manage EEPROM by making sure everything has
// its own index.
enum EEPROMIndices { GENESIS_EEPROM };

// Set up USB HID gamepads
SegaController32U4  gen_controller(GENESIS_EEPROM);
N64Controller       n64_controller;
N64_status_packet   N64Data;

// Controllers
uint32_t  controllerData[2][2]  = {{0,0},{0,0}};
uint32_t  axisIndicator[32]     = {0,0,0,0,1,1,1,1,0,0,0,0,0,0,0,0,0,0,0,0,0,0,0,0,0,0,0,0,0,0,0,0};
uint16_t  currentGenesisState   = 0;
bool      nttActive             = false;

uint32_t  dataMaskNES[8] =        {0x02,   // A
                                   0x01,   // B
                                   0x40,   // Start 
                                   0x80,   // Select
                                   UP,     // D-Up
                                   DOWN,   // D-Down
                                   LEFT,   // D-Left
                                   RIGHT   // D-Right
                                   }; 

// Power Pad D4
uint32_t  dataMaskPowerPadD4[8] = {0x08,    // PowerPad #4
                                   0x04,    // PowerPad #3
                                   0x800,   // PowerPad #12
                                   0x80,    // PowerPad #8
                                   NODATA,  // No Data
                                   NODATA,  // No Data
                                   NODATA,  // No Data
                                   NODATA   // No Data
                                   }; 

// Power Pad D3
uint32_t  dataMaskPowerPadD3[8] = {0x02,   // PowerPad #2
                                   0x01,   // PowerPad #1
                                   0x10,   // PowerPad #5
                                   0x100,  // PowerPad #9
                                   0x20,   // PowerPad #6
                                   0x200,  // PowerPad #10
                                   0x400,  // PowerPad #11
                                   0x40    // PowerPad #7
                                   }; 

uint32_t  dataMaskSNES[32] =      {0x01,    // B
                                   0x04,    // Y
                                   0x40,    // Start   
                                   0x80,    // Select
                                   UP,      // D-Up
                                   DOWN,    // D-Down
                                   LEFT,    // D-Left
                                   RIGHT,   // D-Right
                                   0x02,    // A
                                   0x08,    // X
                                   0x10,    // L
                                   0x20,    // R
                                   NODATA,  // SNES Control Bit
                                   NTT_BIT, // NTT Indicator Bit
                                   NODATA,  // SNES Control Bit
                                   NODATA,  // SNES Control Bit
                                   0x100,   // NTT 0
                                   0x200,   // NTT 1
                                   0x400,   // NTT 2
                                   0x800,   // NTT 3
                                   0x1000,  // NTT 4
                                   0x2000,  // NTT 5
                                   0x4000,  // NTT 6
                                   0x8000,  // NTT 7
                                   0x10000, // NTT 8
                                   0x20000, // NTT 9
                                   0x40000, // NTT *
                                   0x80000, // NTT #
                                   0x100000,// NTT .
                                   0x200000,// NTT C
                                   NODATA,  // NTT No Data
                                   0x800000,// NTT End Comms
                                   };

void setup() 
{
  n64_controller.N64_init();

  // N64 Data pin setup
  DDRD  &= ~B00010000; // inputs
  PORTD |=  B00010000; // enable internal pull-ups

  // On Board TX LED
  DDRD  |= B00100000; // output
  PORTD |= B00100000; // high

  // On Board RX LED
  DDRB  |= B00000001; // output
  PORTB |= B00000001; // high
  
  // Setup NES / SNES latch and clock pins (2/3 or PD1/PD0)
  DDRD  |=  B00000011; // output
  PORTD &= ~B00000011; // low

  // Setup NES / SNES data pins (A0/A1 or PF6/PF7)
  DDRF  &= ~B11000000; // inputs
  PORTF |=  B11000000; // enable internal pull-ups

  // Setup NES PowerPad data pins (8/9 or PB4/PB5)
  DDRB  &= ~B00110000; // inputs
  PORTB |=  B00110000; // enable internal pull-ups

  // Setup power pin (DB9 Pin 5) as output high (PB2)
  DDRB  |= B00000100; // output
  PORTB |= B00000100; // high
  
  SetupHardware();
  GlobalInterruptEnable();
}
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

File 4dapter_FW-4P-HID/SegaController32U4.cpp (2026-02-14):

/*
 * SegaController32U4.cpp — Genesis/Mega Drive controller (DB9) for 4dapter
 *
 * Copyright (C) 2026 4dapter project
 *
 * Original Genesis/MD controller code by Jon Thysell (2017); interfacing
 * largely rewritten by Mikael Norrgård. This version modified for 4dapter.
 *
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
 * You should have received a copy of the GNU General Public License
 * along with this program.  If not, see <https://www.gnu.org/licenses/>.
 */

#include "Arduino.h"
#include "SegaController32U4.h"

SegaController32U4::SegaController32U4()
{
  // Setup select pin as output high (7, PE6)
  DDR_SELECT |= MASK_SELECT; // output
  PORT_SELECT |= MASK_SELECT; // high

  // Setup input pins (A0,A1,A2,A3,14,15 or PF7,PF6,PF5,PF4,PB3,PB1)
  DDRF &= ~B00110000; // input
  PORTF |= B00110000; // high to enable internal pull-up
  DDRB &= ~B00001010; // input
  PORTB |= B00001010; // high to enable internal pull-up
  DDRC &= ~B01000000; // input
  PORTC |= B01000000; // high to enable internal pull-up
  DDRD &= ~B10000000; // input
  PORTD |= B10000000; // high to enable internal pull-up

  _inputReg1 = 0;
  _inputReg2 = 0;
  _inputReg3 = 0;
  _inputReg4 = 0;
  _currentState = 0;
  _connected = 0;
  _sixButtonMode = false;
  _ignoreCycles = 0;
  _pinSelect = true;
}

word SegaController32U4::updateState()
{
  // "Normal" Six button controller reading routine, done a bit differently in this project
  // Cycle  TH out  TR in  TL in  D3 in  D2 in  D1 in  D0 in
  // 0      LO      Start  A      0      0      Down   Up
  // 1      HI      C      B      Right  Left   Down   Up
  // 2      LO      Start  A      0      0      Down   Up      (Check connected and read Start and A in this cycle)
  // 3      HI      C      B      Right  Left   Down   Up      (Read B, C and directions in this cycle)
  // 4      LO      Start  A      0      0      0      0       (Check for six button controller in this cycle)
  // 5      HI      C      B      Mode   X      Y      Z       (Read X,Y,Z and Mode in this cycle)
  // 6      LO      ---    ---    ---    ---    ---    Home    (Home only for 8bitdo wireless gamepads)
  // 7      HI      ---    ---    ---    ---    ---    ---

  // Set the select pin low/high
  _pinSelect = !_pinSelect;
  (!_pinSelect) ? PORT_SELECT &= ~MASK_SELECT : PORT_SELECT |= MASK_SELECT; // Set LOW on even cycle, HIGH on uneven cycle

  // Short delay to stabilise outputs in controller
  delayMicroseconds(SC_CYCLE_DELAY);

  // Read input register(s)
  _inputReg1 = PINF;
  _inputReg2 = PINB;
  _inputReg3 = PINC;
  _inputReg4 = PIND;

  if(_ignoreCycles <= 0)
  {
    if(_pinSelect) // Select pin is HIGH
    {
      if(_connected)
      {
        // Check if six button mode is active
        if(_sixButtonMode)
        {
          // Read input pins for X, Y, Z, Mode
          (bitRead(_inputReg3, DB9_PIN1_BIT) == LOW) ? _currentState |= SC_BTN_Z : _currentState &= ~SC_BTN_Z;
          (bitRead(_inputReg4, DB9_PIN2_BIT) == LOW) ? _currentState |= SC_BTN_Y : _currentState &= ~SC_BTN_Y;
          (bitRead(_inputReg1, DB9_PIN3_BIT) == LOW) ? _currentState |= SC_BTN_X : _currentState &= ~SC_BTN_X;
          (bitRead(_inputReg1, DB9_PIN4_BIT) == LOW) ? _currentState |= SC_BTN_MODE : _currentState &= ~SC_BTN_MODE;
          _sixButtonMode = false;
          _ignoreCycles = 2; // Ignore the two next cycles (cycles 6 and 7 in table above)
        }
        else
        {
          // Read input pins for Up, Down, Left, Right, B, C
          (bitRead(_inputReg3, DB9_PIN1_BIT) == LOW) ? _currentState |= SC_BTN_UP : _currentState &= ~SC_BTN_UP;
          (bitRead(_inputReg4, DB9_PIN2_BIT) == LOW) ? _currentState |= SC_BTN_DOWN : _currentState &= ~SC_BTN_DOWN;
          (bitRead(_inputReg1, DB9_PIN3_BIT) == LOW) ? _currentState |= SC_BTN_LEFT : _currentState &= ~SC_BTN_LEFT;
          (bitRead(_inputReg1, DB9_PIN4_BIT) == LOW) ? _currentState |= SC_BTN_RIGHT : _currentState &= ~SC_BTN_RIGHT;
          (bitRead(_inputReg2, DB9_PIN6_BIT) == LOW) ? _currentState |= SC_BTN_B : _currentState &= ~SC_BTN_B;
          (bitRead(_inputReg2, DB9_PIN9_BIT) == LOW) ? _currentState |= SC_BTN_C : _currentState &= ~SC_BTN_C;
        }
      }
      else // No Mega Drive controller is connected, use SMS/Atari mode
      {
        // Clear current state
        _currentState = 0;

        // Read input pins for Up, Down, Left, Right, Fire1, Fire2
        if (bitRead(_inputReg3, DB9_PIN1_BIT) == LOW)
        {
          _currentState |= SC_BTN_UP;
        }
        if (bitRead(_inputReg4, DB9_PIN2_BIT) == LOW)
        {
          _currentState |= SC_BTN_DOWN;
        }
        if (bitRead(_inputReg1, DB9_PIN3_BIT) == LOW)
        {
          _currentState |= SC_BTN_LEFT;
        }
        if (bitRead(_inputReg1, DB9_PIN4_BIT) == LOW)
        {
          _currentState |= SC_BTN_RIGHT;
        }
        if (bitRead(_inputReg2, DB9_PIN6_BIT) == LOW)
        {
          _currentState |= SC_BTN_A;
        }
        if (bitRead(_inputReg2, DB9_PIN9_BIT) == LOW)
        {
          _currentState |= SC_BTN_B;
        }
      }
    }
    else // Select pin is LOW
    {
      // Check if a controller is connected
      _connected = (bitRead(_inputReg1, DB9_PIN3_BIT) == LOW && bitRead(_inputReg1, DB9_PIN4_BIT) == LOW);

      // Check for six button mode
      _sixButtonMode = (bitRead(_inputReg3, DB9_PIN1_BIT) == LOW && bitRead(_inputReg4, DB9_PIN2_BIT) == LOW);

      // Read input pins for A and Start
      if(_connected)
      {
        if(!_sixButtonMode)
        {
          (bitRead(_inputReg2, DB9_PIN6_BIT) == LOW) ? _currentState |= SC_BTN_A : _currentState &= ~SC_BTN_A;
          (bitRead(_inputReg2, DB9_PIN9_BIT) == LOW) ? _currentState |= SC_BTN_START : _currentState &= ~SC_BTN_START;
        }
      }
    }
  }
  else
  {
    if(_ignoreCycles-- == 2) // Decrease the ignore cycles counter and read 8bitdo home in first "ignored" cycle, this cycle is unused on normal 6-button controllers
    {
      (bitRead(_inputReg3, DB9_PIN1_BIT) == LOW) ? _currentState |= SC_BTN_HOME : _currentState &= ~SC_BTN_HOME;
    }
  }

  return _currentState;
}

word SegaController32U4::getFinalState()
{
  return _currentState;
}

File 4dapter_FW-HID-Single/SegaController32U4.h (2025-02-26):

//
// SegaController32U4.h
//
// Authors:
//       Jon Thysell <thysell@gmail.com>
//       Mikael Norrgård <mick@daemonbite.com>
//
// Copyright (c) 2017 Jon Thysell <http://jonthysell.com>
//
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
#ifndef SegaController32U4_h
#define SegaController32U4_h

#define DDR_SELECT   DDRE
#define PORT_SELECT  PORTE
#define MASK_SELECT  B01000000
#define GEN_MISTER   false

/*
  SC_BTN_A     = 64,
  SC_BTN_B     = 16,
  SC_BTN_C     = 32,
  SC_BTN_X     = 256,
  SC_BTN_Y     = 128,
  SC_BTN_Z     = 512,
 */


#if (GEN_MISTER == true)  // MiSTer Config
enum
{
  SC_BTN_UP    = 1,
  SC_BTN_DOWN  = 2,
  SC_BTN_LEFT  = 4,
  SC_BTN_RIGHT = 8,
  SC_BTN_A     = 32,
  SC_BTN_B     = 16,
  SC_BTN_C     = 512,
  SC_BTN_X     = 128,
  SC_BTN_Y     = 64,
  SC_BTN_Z     = 256,
  SC_BTN_MODE  = 1024,
  SC_BTN_START = 2048,
  SC_BTN_HOME  = 4096,
  SC_BIT_SH_UP    = 0,
  SC_BIT_SH_DOWN  = 1,
  SC_BIT_SH_LEFT  = 2,
  SC_BIT_SH_RIGHT = 3,
  DB9_PIN1_BIT = 6,
  DB9_PIN2_BIT = 7,
  DB9_PIN3_BIT = 5,
  DB9_PIN4_BIT = 4,
  DB9_PIN6_BIT = 3,
  DB9_PIN9_BIT = 1
};
#else // Batocera Config
enum
{
  SC_BTN_UP    = 1,
  SC_BTN_DOWN  = 2,
  SC_BTN_LEFT  = 4,
  SC_BTN_RIGHT = 8,
  SC_BTN_A     = 64,
  SC_BTN_B     = 16,
  SC_BTN_C     = 32,
  SC_BTN_X     = 256,
  SC_BTN_Y     = 128,
  SC_BTN_Z     = 512,
  SC_BTN_MODE  = 1024,
  SC_BTN_START = 2048,
  SC_BTN_HOME  = 4096,
  SC_BIT_SH_UP    = 0,
  SC_BIT_SH_DOWN  = 1,
  SC_BIT_SH_LEFT  = 2,
  SC_BIT_SH_RIGHT = 3,
  DB9_PIN1_BIT = 6,
  DB9_PIN2_BIT = 7,
  DB9_PIN3_BIT = 5,
  DB9_PIN4_BIT = 4,
  DB9_PIN6_BIT = 3,
  DB9_PIN9_BIT = 1
};
#endif

const byte SC_CYCLE_DELAY = 10; // Delay (µs) between setting the select pin and reading the button pins

class SegaController32U4 
{
  public:
    // |eeprom_index| is the eeprom storage reserved for this instance.
    SegaController32U4(int eeprom_index);
    word updateState(void);
    word getFinalState(void);

  private:
    // Should A and B and X and Y be swapped?
    void toggleMisterMode(void);
    bool isMisterMode(void);

    const int _eeprom_index;

    // This acts as a cache to not routinely read EEPROM.
    bool _misterMode;

    word _currentState;
    word _previousState;

    boolean _pinSelect;

    byte _ignoreCycles;

    boolean _connected;
    boolean _sixButtonMode;

    byte _inputReg1;
    byte _inputReg2;
    byte _inputReg3;
    byte _inputReg4;
};

#endif

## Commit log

2023-05-15 Added KiCad Projects
    [4dapter-B_Cu.gbr, 4dapter-B_Mask.gbr, 4dapter-Edge_Cuts.gbr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]
2023-05-15 Gerber files added
2023-09-16 Modified N64 value mapping logic
    Modified N64 value mapping logic to set condition to switch between N64 controller raw value and HID 8-bit max (-128 to +127)
2023-09-23 Adjust N64 Select Button Location
2023-10-08 Fix issue with N64 X-axis rolling over incorrectly
    [4dapter_FW-HID.ino]
2025-01-08 Update N64 timeouts
    Add support for early Brawler 64 Wireless controllers that have almost 40us delay after the initial query before receiving controller data.
2025-02-22 Fix bug with N64 "special" button input mapping
    [4dapter_FW-HID.ino]
2025-02-22 Fix issue with "select" and remove N64 "special"
    [4dapter_FW-HID-Single.ino]
2025-02-23 Add bool to set N64 C-Stick to individual buttons
2025-02-23 button config for Batocera/Retroarch
2025-02-23 add instructions for Batocera
    [es_last_input.cfg]
2025-03-18 Fix for `select` button as hotkey in Batocera. Update mapping instructions
    [4dapter_FW-HID-Single.ino]

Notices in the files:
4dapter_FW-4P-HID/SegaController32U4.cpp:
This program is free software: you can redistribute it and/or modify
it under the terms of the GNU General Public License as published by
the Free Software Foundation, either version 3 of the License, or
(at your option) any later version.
